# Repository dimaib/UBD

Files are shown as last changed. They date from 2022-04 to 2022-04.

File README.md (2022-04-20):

# Wireless access device
## Description
This system allows you to distribute people between warehouse equipment and give permission to control certain types of machines. It also allows you to take into account the working hours of employees and conduct convenient analytics according to these hours.
- The system consists of a device that controls the warehouse machine directly
	>The printed circuit board and circuit diagram of the device are created in [KiCad](https://www.kicad.org) 
	Firmware created in Keil uVision for ARM in C languages
- Server that receives data from devices and adds this data to the database
	>The server part was created in Visual Studio C ++, as a console application
- Client application that connects to the database and in a convenient form, displays
	>The client application was created in Visual Studio C#, as an application with a user interface

## Main view PCB
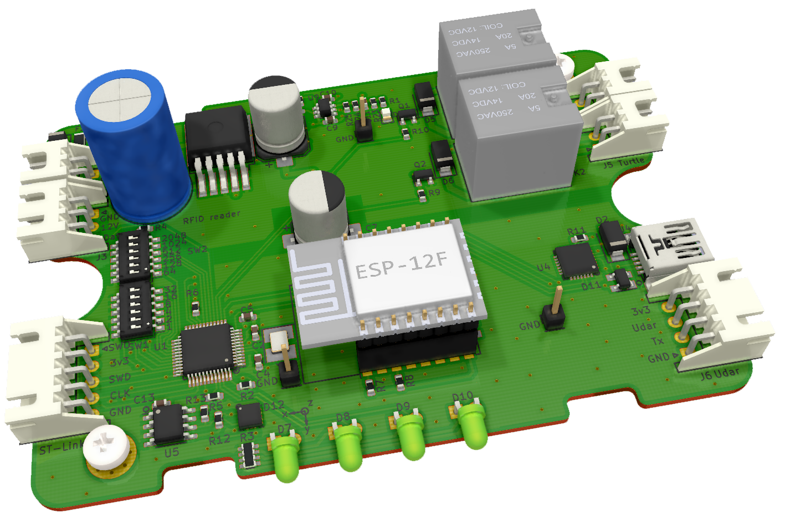
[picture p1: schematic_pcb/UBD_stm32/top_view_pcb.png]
PCB top

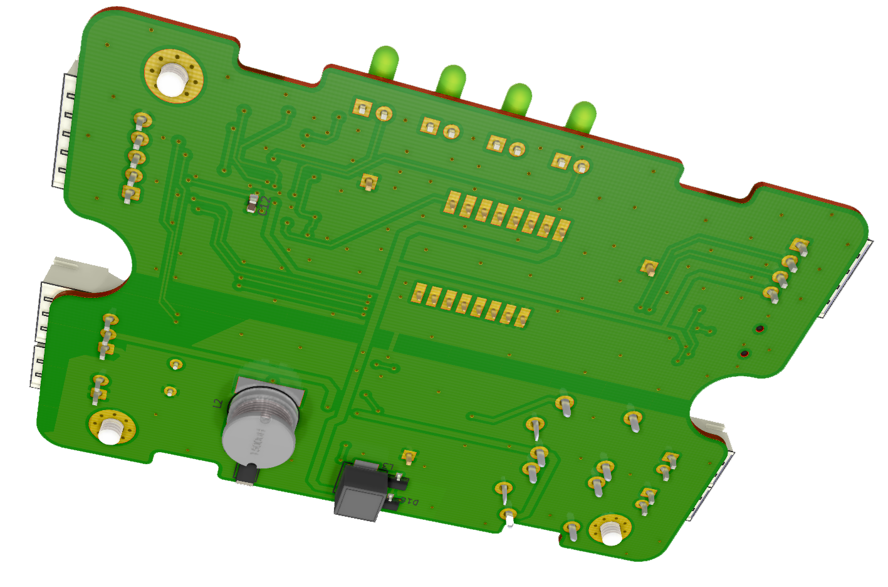
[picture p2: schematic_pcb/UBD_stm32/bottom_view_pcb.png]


## Main client app
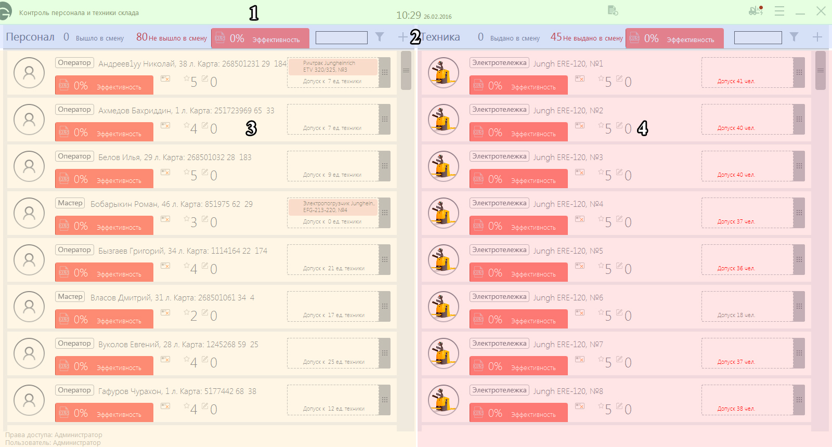
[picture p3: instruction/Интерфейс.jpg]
Main client app


>1. _Control panel_
>2. _General statistics panel for the warehouse_
>3. _Personnel control panel_
>4. _Equipment control panel_

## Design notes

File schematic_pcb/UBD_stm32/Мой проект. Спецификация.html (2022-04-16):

### Мой проект. Cпецификация

N | Название | Полное наименование | Количество | Обозначение
1 | +3.3V | | 18 | #PWR01 - #PWR03, #PWR05, #PWR011, #PWR013, #PWR015, #PWR020, #PWR022, #PWR0101 - #PWR0103, #PWR0106, #PWR0119, #PWR0120, #PWR0123, #PWR0125, #PWR0134
2 | +3V3 | | 1 | #PWR0126
3 | +5V | | 3 | #PWR019, #PWR021, #PWR024
4 | GND | | 32 | #PWR04, #PWR06 - #PWR08, #PWR010, #PWR012, #PWR014, #PWR016 - #PWR018, #PWR023, #PWR025, #PWR0104, #PWR0105, #PWR0107 - #PWR0112, #PWR0114 - #PWR0117, #PWR0121, #PWR0122, #PWR0124, #PWR0127, #PWR0128, #PWR0131 - #PWR0133
5 | +12V | | 5 | #PWR09, #PWR0113, #PWR0118, #PWR0129, #PWR0130
6 | 100 | | 1 | C1
7 | 220 | | 2 | C2, C3
8 | 1uF | | 3 | C4 - C6
9 | 100nF | | 1 | C7
10 | D_Schottky | | 3 | D1 - D3
11 | Red | | 2 | D12, D13
12 | LED | | 1 | D4
13 | D_Schottky | | 2 | D5, D6
14 | Red | | 4 | D7 - D10
15 | Fuse | | 1 | F1
16 | Для программирования | | 1 | J1
17 | Входной клемник | | 1 | J2
18 | Считыватель | | 1 | J3
19 | USB_B_Micro | | 1 | J4
20 | На релейной плате | | 1 | J5
21 | На основной плате | | 1 | J6
22 | G5LE-1 | | 2 | K1, K2
23 | 1000 | | 1 | L1
24 | 2200 | | 1 | L2
25 | BC817 | | 4 | Q1 - Q4
26 | 360 | | 8 | R1, R7 - R12, R15
27 | 1k | | 1 | R13
28 | 10k | | 6 | R2, R4 - R6, R14, R16
29 | 360 | | 1 | R3
30 | Выбор адреса | | 1 | SW1
31 | LM2576HVS-3.3 | | 1 | U1
32 | LM2576HVS-12 | | 1 | U2
33 | ESP-12F | | 1 | U3
34 | ATmega128-16AU | | 1 | U4
35 | LIS302 | | 1 | U5
36 | CH340G | | 1 | U6
37 | AP1117-33 | | 1 | U7
38 | 14.7456MHz | | 1 | Y1
39 | 12MHz | | 1 | Y2

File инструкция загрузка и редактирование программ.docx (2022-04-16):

Прошивка контроллеров Atmega.

На базе данных контроллеров разработаны устройства УБД и датчик удара. Для программирования этих контроллеров требуется следующий инструментарий:

- программатор для контроллеров AVR. Например, USBASP. Распиновка разъёма данного программатора, это стандартный ISP разъём:

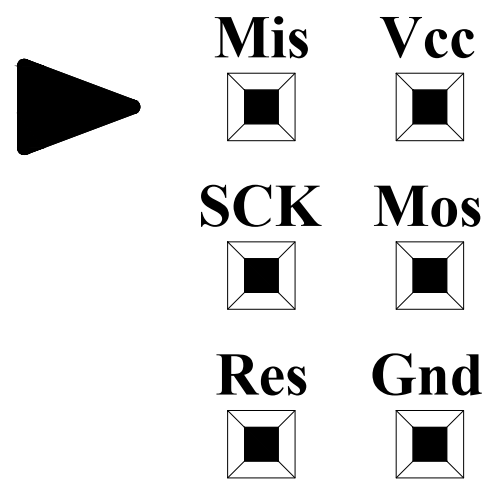
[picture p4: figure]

- переходник USB-UART. Например, на базе микросхемы ch340.
- программа для редактирования и компилирования программы контроллера BASCOM
- программа для редактирования и компилирования программы контроллера Atmel Studio
- программа для загрузки программы в контроллер ProgISP (стабильно работает 1.72 версия)
- программа для получения данных из серийного порта SerialMonitor (или любая аналогичная)
- программа для просмотра и редактирования схем и печатных плат проектов Kicad 5.1.4.1(не ниже)
- в некоторых случаях понадобится Arduino IDE, для редактирования и загрузки программ в Arduino

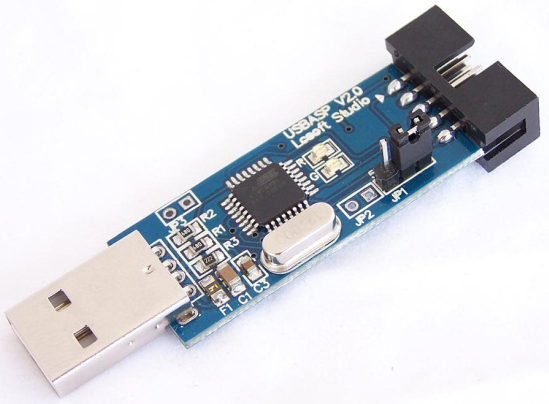
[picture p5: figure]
Картинки по запросу USBASP kicad

Для прошивки контроллера следует выбрать напряжение питания на программаторе, с помощью перемычки, 5В или 3.3В. Для того, что бы удостовериться в выборе напряжения, следует померить его на разъёме программатора. На рисунке показан общий вид программатора и перемычка выбора напряжения питания программируемого устройства.

Далее подключив разъём программатора к ISP разъёму устройства требуется запустить программу ProgISP. Общий внешний вид программы и необходимые настройки показаны на рисунке ниже.

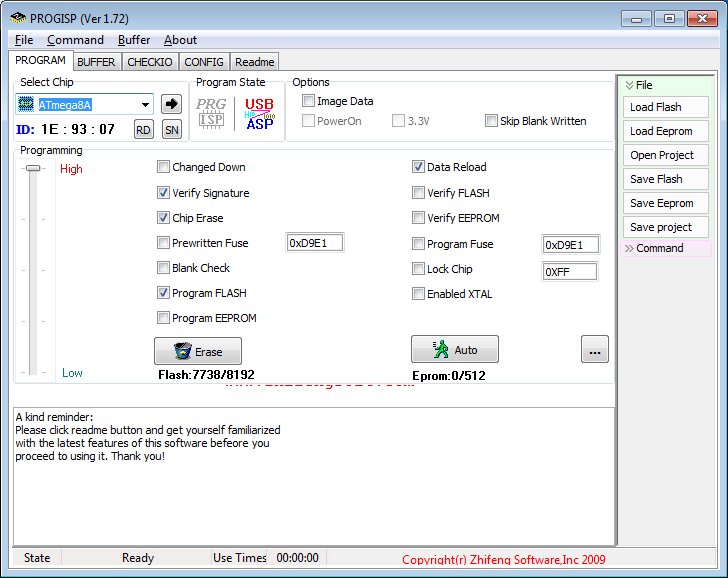
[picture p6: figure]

После запуска программы требуется выбрать программируемый контроллер из списка в поле “Select Chip”. Для датчика удара это Atmega8 или Atmega8A. Для УБД это Atmega128 или Atmega128A.

Далее требуется проверить правильность подключения программатора и работоспособность контроллера. Для этого достаточно считать его настройки (FUSES или фьюзы). Делается это следующим образом:

Фьюзы

Требуется зайти в окно настройки фьюзов нажатием на соответствующее поле.

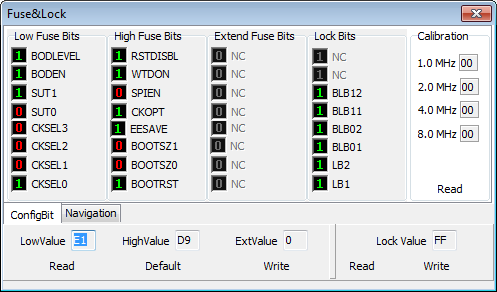
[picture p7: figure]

В открывшемся окне (Fuse&Lock) нажатием кнопки Read будут прочитаны настройки контроллера и подставлены в поля LowValue и HighValue. Возможные проблемы:

Ошибка “Programmer can not be found.” Говорит о том, что программатор либо не подключен, либо завис. Решается это подключением программатора или переподключением его в разъём USB.

Ошибка “Chip Enable Program Error” говорит о том, что контроллер не может быть прочитан. Причин этому может быть множество. Вот некоторые из них:

Контроллер плохо припаян к плате; на контроллер не приходит питание; в контролер загружены не корректные фьюзы (можно сразу менять контроллер); не правильно подключен разъём программатора; контроллер выведен из строя…….. и тд.

Также при множественном чтении настроек в поля LowValue и HighValue могут заноситься постоянно разные данные, это говорит о плохом питающем напряжении, к примеру, на контроллер не приходит линия Gnd или Vcc.

Если есть возможность несколько раз стабильно прочитать фьюзы из контроллера это говорит о том, что он исправен и готов к прошивке.

Для этого сначала требуется настроить эти самые фьюзы с помощью полей LowValue и HighValue. [Датчик удара: LowValue=E4 HighValue=D9] [УБД: LowValue=FF HighValue=C1 ExtValue=FF]. После заполнения данных полей нажать на кнопку “Write”. Если всё прошло без ошибок, то для контроля можно несколько раз прочитать фьюзы. После закрываем окно Fuse&Lock.

Далее требуется выбрать hex-файл скомпилированной программы. Это делается нажатием кнопки “Load Flash”, и в открывшемся окне указать путь до hex-файла.

Датчик удара […\UBD\Программы\Датчик удара\Accel_LIS302\LIS302DL.hex]

УБД […\UBD\Программы\Программа МК\WiFi.hex]

Чтобы загрузить hex-файл в контроллер нажимаем кнопку “Auto”, после завершения загрузки контроллер автоматически начнёт работу.

Редактирование программы для УБД

Проект для УБД можно открыть и редактировать средой BASCOM IDE.

Запустив данную среду программирования, следует открыть файл проекта. Файл-Открыть в окне появившемся окне указать тип файлов “Project files (*.prj)”. Путь …\UBD\Программы\Программа МК\UBD.prj.

В данном проекте, для настойки работоспособности устройства требуется настроить следующие константы и переменные:

Plata версия платы. 1-старая плата, 2-новая плата [WiFi]

Debug_info вывод отладочной информации в UART [WiFi]

Print_info вывод информации о состоянии устройства в UART [WiFi]

Wifi номер дампа для сетевых настроек [Vars]

Ud_eep если 0-не сохранять удар в eeprom, если 1-сохранять удар в eeprom [Vars]

Ud_on если 0-удар отключен, если 1-удар включен [Vars]

Ig_ud_off отключение зажигания при ударе 0-не отключается, 1-отключается [Vars]

Дампы сетевых настроек. Имеются три дампа в файле Data:

Ip_adr дамп IP-адресов сервера

Wifi_ap дамп имён точек доступа

Wifi_pass дамп паролей от точек доступа

Нумерация записей в дампе начинаются с нуля и выбираются с помощью переменной Wifi. К примеру, если задать данной переменной значение 2, то IP-сервера будет 192.168.0.30, имя точки доступа Kslift, пароль от точки доступа A0C4B096D4.

Ip_adr: IP-адреса сервера [Data]

Data _

"10.11.22.50", _

"10.0.0.3", _

"192.168.0.30", _

"192.168.1.20",

Wifi_ap: Имена точек доступа

Data _

"MJR-Sklad", _

"NETGEAR", _

"Kslift", _

"dimaib"

Wifi_pass: Пароли точек доступа

Data _

"DabuDaDe", _

"111222333444", _

"A0C4B096D4", _

"230988DVG"

После всех настроек сделанных в прошивке следует нажать клавишу F7, что запустит компиляцию. После удачной компиляции программу следует загрузить в контроллер.

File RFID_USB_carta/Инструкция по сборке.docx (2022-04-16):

После монтажа компонентов на печатную плату следует подключить её к считывателю RFID-карт MATRIX II. На рисунке 1 представлены места пайки.

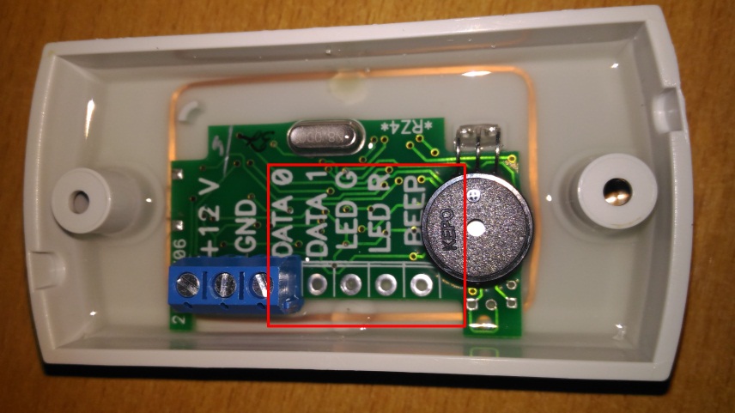
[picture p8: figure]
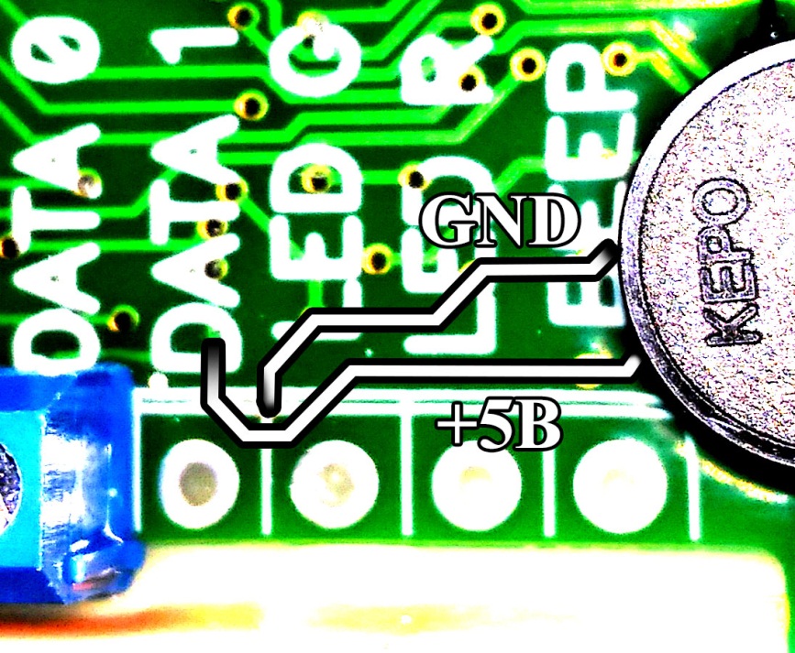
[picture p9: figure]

Клемма Rfid на плате соединяется с клеммой DATA 0

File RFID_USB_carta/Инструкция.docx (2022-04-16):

| Содержание

1. Назначение устройства
2. Комплектность
3. Технические характеристики

| Назначение устройства

Данное устройство предназначено для передачи на персональный компьютер в поле ввода идентификационного номера карты (RFID)

| Технические характеристики*

Длина кабеля | 1 метр
Размеры (ДхШхВ) | 85х43х17
Питание | 5В (USB)

| Общие указания по использованию устройства

Для работы устройства требуется наличие USB порта в ПК, с которым оно используется.

При первом подключении устройства в USB порт, происходит автоматическая установка драйверов. После установки устройство определяется как “Устройство ввода”. Круглый светодиод на лицевой панели отображает состояние NumLock в системе.

Что бы вставить идентификатор карты в текстовое поле с помощью данного устройства требуется активировать NumLock (светодиод NumLock на клавиатуре горит), далее вставить устройство в USB порт и дождаться пока загорится круглый, красный светодиод на лицевой панели, это свидетельствует, что устройство готово к работе. При горящем круглом светодиоде на передней панели, следует приложить карту к устройству, после этого в текстовое поле вставится её идентификационный код.

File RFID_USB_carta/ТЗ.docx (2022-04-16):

USB устройство для считывания RFID-карты

Требуется устройство для считывания RFID-карты и передачи данных по USB. USB устройство должно определяться как HID устройство ввода. Передача считанной карты происходит в активное текстовое поле в следующем формате: FF FF FF FF FF FF FF FF.

Питание устройства осуществляется от USB кабеля.

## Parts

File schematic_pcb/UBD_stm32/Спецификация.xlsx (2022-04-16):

Обозначение на схеме | Номинал | Корпус | Артикул | Ссылка | Цена, руб | Кол-во | Цена общая
C1 | 100uF | Capacitor_THT:C_Radial_D12.5mm_H20.0mm_P5.00mm | 9000291267 | https://www.chipdip.ru/product0/9000291267 | 28.00 ₽ | 1 | 28.00 ₽
> C3, C7 | 220uF | Capacitor_SMD:CP_Elec_8x10.5 | ECAP SMD, 220 мкФ, 25В | https://www.chipdip.ru/product0/57194 | 24.00 ₽ | 2 | 48.00 ₽
> C2, C4, C5 | 100n | Capacitor_SMD:C_0603_1608Metric | GRM188R71E104KA01D | https://www.chipdip.ru/product/grm188r71e104ka01d | 3.00 ₽ | 3 | 9.00 ₽
> C6, C12, C13 | 1uF | Capacitor_SMD:C_0603_1608Metric | GRM188R61E105KAADD | https://www.chipdip.ru/product/grm188r61e105k | 5.00 ₽ | 3 | 15.00 ₽
C8 | 10uF | Capacitor_SMD:C_0603_1608Metric | GRM188R61E106MA73D | https://www.chipdip.ru/product/grm21br61c106ke15l | 12.00 ₽ | 1 | 12.00 ₽
C9 | 0.01uF | Capacitor_SMD:C_0603_1608Metric | MLCC0.01uFX7R50V10%0603 | https://www.chipdip.ru/product0/9000143994 | 3.00 ₽ | 1 | 3.00 ₽
C10 | 22uF | Capacitor_SMD:C_0603_1608Metric | GRM188R60G226MEA0L | https://www.chipdip.ru/product/grm188r60g226mea0l | 13.00 ₽ | 1 | 13.00 ₽
C11 | 1000pF | Capacitor_SMD:C_0603_1608Metric | GRM1885C1H102JA01D | https://www.chipdip.ru/product/grm1885c1h102j | 2.00 ₽ | 1 | 2.00 ₽
> D1-D3, D5, D6 | Диод Шоттки | UBD:D_SMA | SS16 | https://www.chipdip.ru/product/ss16 | 4.00 ₽ | 5 | 20.00 ₽
D4 | LED | LED_SMD:LED_0805_2012Metric | KP-2012EC | https://www.chipdip.ru/product/kp-2012ec | 9.00 ₽ | 1 | 9.00 ₽
D7 | Светодиод красный | UBD:LED_D3.0mm_Horizontal_O1.27mm_Z2.0mm | GNL-3014SRD | https://www.chipdip.ru/product/gnl-3014srd | 4.00 ₽ | 1 | 4.00 ₽
D8 | Светодиод жёлтый | UBD:LED_D3.0mm_Horizontal_O1.27mm_Z2.0mm | GNL-3012GD | https://www.chipdip.ru/product/gnl-3012gd | 5.00 ₽ | 1 | 5.00 ₽
D9 | Светодиод зелёный | UBD:LED_D3.0mm_Horizontal_O1.27mm_Z2.0mm | GNL-3014YT | https://www.chipdip.ru/product/gnl-3014yt | 5.00 ₽ | 1 | 5.00 ₽
D10 | Светодиод синий | UBD:LED_D3.0mm_Horizontal_O1.27mm_Z2.0mm | GNL-3014UBD-TL | https://www.chipdip.ru/product/gnl-3014ubd-tl | 11.00 ₽ | 1 | 11.00 ₽
D11 | SP0503 | Package_TO_SOT_SMD:SOT-143 | SP0503BAHTG | https://www.chipdip.ru/product/sp0503bahtg | 44.00 ₽ | 1 | 44.00 ₽
> D15, D16 | Диод Шоттки | Diode_SMD:D_SOT-23_ANK | ZHCS1000TA | https://www.chipdip.ru/product/zhcs1000ta-sot23 | 4.00 ₽ | 2 | 8.00 ₽
F1 | Fuse 2A | Resistor_SMD:R_1206_3216Metric | Fuse 1.1A smd | https://ru.aliexpress.com/item/100-0805-1206-1812-0-05A-2A-0-1A-0-2A-0-5A-0/32894932841.html?s=p | 6.00 ₽ | 1 | 6.00 ₽
J1 | ST-Link | Connector_JST:JST_XH_S5B-XH-A_1x05_P2.50mm_Horizontal | ??? | https://www.tme.eu/ru/details/s5b-xh-a/razemy-signalnye-rastr-2-50mm/jst/s5b-xh-a-lf-sn https://www.tme.eu/ru/details/nx2501-05pfs/razemy-signalnye-rastr-2-50mm/joint-tech/a2501h-5p | 6+6 | 1 | 12.00 ₽
J2 | Ignition | Connector_JST:JST_XH_S2B-XH-A_1x02_P2.50mm_Horizontal | CWF-2R (DS1069-2 MR-A) CHU-2 (DS1069-2 F) | https://www.chipdip.ru/product/cwf-2r-ds1069-2-mr https://www.chipdip.ru/product/chu-2 | 6+6 | 1 | 12.00 ₽
J3 | Считыватель | Connector_JST:JST_XH_S3B-XH-A_1x03_P2.50mm_Horizontal | CWF-3R (DS1069-3 MR-A) CHU-3 (DS1069-3 F) | https://www.chipdip.ru/product/cwf-3r https://www.chipdip.ru/product/chu-3 | 5+5 | 1 | 10.00 ₽
J4 | USB_B_Micro | Connector_USB:USB_Mini-B_Lumberg_2486_01_Horizontal | MiniUSB-A | https://www.chipdip.ru/product/miniusb-a-5pin | 22.00 ₽ | 1 | 22.00 ₽
J5 | Turtle | Connector_JST:JST_XH_S2B-XH-A_1x02_P2.50mm_Horizontal | CWF-2R (DS1069-2 MR-A) CHU-2 (DS1069-2 F) | https://www.chipdip.ru/product/cwf-2r-ds1069-2-mr https://www.chipdip.ru/product/chu-2 | 6+6 | 1 | 12.00 ₽
J6 | Удар | Connector_JST:JST_XH_S4B-XH-A_1x04_P2.50mm_Horizontal | CWF-4R (DS1069-4 MR-A) CHU-4 (DS1069-4 F) | https://www.chipdip.ru/product/cwf-4r-ds1069-4-mr https://www.chipdip.ru/product/chu-4 | 6+6 | 1 | 12.00 ₽
J7 | Питание | Connector_JST:JST_XH_S2B-XH-A_1x02_P2.50mm_Horizontal | CWF-2R (DS1069-2 MR-A) CHU-2 (DS1069-2 F) | https://www.chipdip.ru/product/cwf-2r-ds1069-2-mr https://www.chipdip.ru/product/chu-2 | 6+6 | 1 | 12.00 ₽
> K1, K2 | NRP-18 | UBD:Relay_NRP-18 | NRP-18-C-12D-H | https://www.chipdip.ru/product/nrp-18-c-12d-s-h | 47.00 ₽ | 2 | 94.00 ₽
L2 | 1500uH | UBD:SDR_1006 | SDR1006-152KL | https://www.chipdip.ru/product/sdr1006-152kl-1500 | 45.00 ₽ | 1 | 45.00 ₽
L3 | 10uH | UBD:L_Vishay_IHLP-2525 | LQH66SN100M03L | https://www.chipdip.ru/product/lqh66sn100m | 74.00 ₽ | 1 | 74.00 ₽
> Q1, Q2 | BC817 | UBD:SOT-23 | BC817.215 | https://www.chipdip.ru/product/bc817.215 | 3.00 ₽ | 2 | 6.00 ₽
> R2, R4-R8, R11-R13, R25 | 10k | Resistor_SMD:R_0603_1608Metric | 0.063Вт 0603 10 кОм, 1% | https://www.chipdip.ru/product0/9000079736 | 0.90 ₽ | 10 | 9.00 ₽
R3 | 330 | Resistor_SMD:R_Array_Convex_4x0603 | CAY16-331J4 4х330 Ом | https://www.chipdip.ru/product/cay16-331j4 | 2.00 ₽ | 1 | 2.00 ₽
> R1, R9, R10 | 360 | Resistor_SMD:R_0603_1608Metric | 0.1Вт 0603 360 Ом, 1% | https://www.chipdip.ru/product0/9000079629 | 0.90 ₽ | 3 | 2.70 ₽
R22 | 100k | Resistor_SMD:R_0603_1608Metric | 0.1Вт 0603 100 кОм, 1% | https://www.chipdip.ru/product0/9000079760 | 0.90 ₽ | 1 | 0.90 ₽
R23 | 1.6k | Resistor_SMD:R_0603_1608Metric | 0.1Вт 0603 1.6 кОм, 1% | https://www.chipdip.ru/product0/770 | 0.90 ₽ | 1 | 0.90 ₽
R24 | 30k | Resistor_SMD:R_0603_1608Metric | 0.1Вт 0603 30 кОм, 1% | https://www.chipdip.ru/product0/9000079747 | 0.90 ₽ | 1 | 0.90 ₽
SW1 | Выбор адреса | Button_Switch_SMD:SW_DIP_SPSTx08_Slide_Omron_A6H-8101_W6.15mm_P1.27mm | NHDS-08 | http://www.platan.ru/cgi-bin/qwery.pl/id=105430408 | 70.00 ₽ | 1 | 70.00 ₽
U1 | STM32F103C8Tx | Package_QFP:LQFP-48_7x7mm_P0.5mm | STM32F103C8T6 | https://www.chipdip.ru/product/stm32f103c8t6 | 110.00 ₽ | 1 | 110.00 ₽
U2 | LM2576HVS-12 | Package_TO_SOT_SMD:TO-263-5_TabPin3 | LM2576HVT-12/NOPB | https://www.chipdip.ru/product/lm2576hvt-12-nopb | 330.00 ₽ | 1 | 330.00 ₽
U3 | ESP-12F | UBD:ESP-12E | ESP-12F | https://ru.aliexpress.com/item/1PCS-ESP-12F-ESP-12E-upgrade-ESP8266-Remote-Serial-Port-WIFI-Wireless-Module-ESP8266-4M-Flash/32808593889.html | 93.00 ₽ | 1 | 93.00 ₽
U4 | CP2102 | Package_DFN_QFN:QFN-28-1EP_5x5mm_P0.5mm_EP3.35x3.35mm | CP2102-GMR | https://www.chipdip.ru/product/cp2102-gmr | 110.00 ₽ | 1 | 110.00 ₽
U5 | AT24CS256 | Package_SO:SOIC-8_3.9x4.9mm_P1.27mm | AT24CS256 | https://www.chipdip.ru/product/at24cs02-sshm-t-microchip | 40.00 ₽ | 1 | 40.00 ₽
U9 | LM2734Y | Package_TO_SOT_SMD:TSOT-23-6 | LM2734YMK | https://www.chipdip.ru/product/lm2734ymk-nopb | 120.00 ₽ | 1 | 120.00 ₽
Y1 | 8.0MHz | UBD:Crystal_SMD_3225-2Pin_3.2x2.5mm_HandSoldering | NX3225GD-8MHz | https://www.chipdip.ru/product0/9000523940 | 13.00 ₽ | 1 | 13.00 ₽

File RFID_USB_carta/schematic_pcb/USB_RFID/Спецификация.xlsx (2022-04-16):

Спецификация для настольного считывателя карт
Наименование |  | Артикул | Ссылка | Кол-во общ | Цена шт | Кол-во | Цена общ
10uF 10V | Capacitor_Tantalum_SMD:CP_EIA-3216-18_Kemet-A | TECAP10/10VA10 | https://www.chipdip.ru/product0/868717967 | 12 | 12.00р. | 1 | 12.00р. | 144.00р.
33pF | Capacitor_SMD:C_0805_2012Metric | GRM2165C1H330JD01D | https://www.chipdip.ru/product/grm2165c1h330j | 24 | 2.00р. | 2 | 4.00р. | 96.00р.
3v6 | Diode_SMD:D_MiniMELF | BZV55C3V6 | https://www.chipdip.ru/product/bzv55c3v6 | 24 | 2.00р. | 2 | 4.00р. | 96.00р.
LED | LED_SMD:LED_0603_1608Metric | TO-1608BC-MYF | https://www.chipdip.ru/product/to-1608bc-myf | 12 | 3.00р. | 1 | 3.00р. | 36.00р.
Program | USB_RFID:PinHeader_2x03_P2.54mm_Vertical | PLD-6 (DS1021-2x3S) | https://www.chipdip.ru/product/pld-6 | 12 | 6.00р. | 1 | 6.00р. | 72.00р.
USB | USB_RFID:RFID | 18-1136 | https://www.chipdip.ru/product/18-1136-usb | 12 | 140.00р. | 1 | 140.00р. | 1680.00р.
10k | Resistor_SMD:R_0603_1608Metric | 0.063Вт 0603 10 кОм, 1% | https://www.chipdip.ru/product0/9000079736 | 12 | 0.90р. | 1 | 0.90р. | 10.80р.
68 | Resistor_SMD:R_0603_1608Metric | 0.063Вт 0603 68 Ом, 1% | https://www.chipdip.ru/product0/9000189750 | 24 | 0.90р. | 2 | 1.80р. | 43.20р.
1.5k | Resistor_SMD:R_0603_1608Metric | 0.063Вт 0603 1.5 кОм, 1% | https://www.chipdip.ru/product0/9000079716 | 12 | 0.90р. | 1 | 0.90р. | 10.80р.
360 | Resistor_SMD:R_0603_1608Metric | 0.063Вт 0603 360 Ом, 1% | https://www.chipdip.ru/product0/9000189778 | 12 | 0.90р. | 1 | 0.90р. | 10.80р.
SW_Push | USB_RFID:SW_SPST_PTS645 | L-KLS7-TS6604-7.0-180-T | https://www.chipdip.ru/product/swt-34 | 12 | 8.00р. | 1 | 8.00р. | 96.00р.
ATmega8-16AU | Package_QFP:TQFP-32_7x7mm_P0.8mm | ATmega8A-AU | https://www.chipdip.ru/product/atmega8a-au | 12 | 90.00р. | 1 | 90.00р. | 1080.00р.
12MHz | Crystal:Crystal_SMD_HC49-SD_HandSoldering | 12.000 МГц имп. HC-49SM | https://www.chipdip.ru/product/12mhz-hc-49sm | 12 | 15.00р. | 1 | 15.00р. | 180.00р.
 |  |  |  |  | Итого: |  | 286.50р. | 3555.60р.

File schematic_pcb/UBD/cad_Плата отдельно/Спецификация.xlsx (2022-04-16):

Наименование | Корпус | Артикул | Ссылка | Цена | Кол-во | Устройств | Цена
100uF | Capacitor_THT:C_Radial_D8.0mm_H11.5mm_P3.50mm | B41851F8107M000 | https://www.chipdip.ru/product0/9000188152 | 14 | 1 | 10 | 140
220uF | Capacitor_SMD:CP_Elec_8x10.5 | ECAP SMD, 220 мкФ, 25В | https://www.chipdip.ru/product0/57194 | 24 | 1 | 10 | 240
1uF | Capacitor_SMD:C_0805_2012Metric | GRM21BR71C105KA01K | https://www.chipdip.ru/product/grm21br71c105k | 4 | 2 | 10 | 80
100nF | Capacitor_SMD:C_0805_2012Metric | MLCC1000pF50VNP05%0805 | https://www.chipdip.ru/product0/522764173 | 4 | 1 | 10 | 40
10uF | Capacitor_SMD:C_0805_2012Metric | GRM21BR71C105KA01K | https://www.chipdip.ru/product/grm21br71c105k | 4 | 3 | 10 | 120
0.01uF | Capacitor_SMD:C_0805_2012Metric | GRM21BR71C105KA01K | https://www.chipdip.ru/product/grm21br71c105k | 4 | 1 | 10 | 40
22uF | Capacitor_SMD:C_0805_2012Metric | GRM21BR71C105KA01K | https://www.chipdip.ru/product/grm21br71c105k | 4 | 1 | 10 | 40
1000pF | Capacitor_SMD:C_0805_2012Metric | GRM21BR71C105KA01K | https://www.chipdip.ru/product/grm21br71c105k | 4 | 1 | 10 | 40
Диод Шоттки | Diode_SMD:D_SMA | SS16 | https://www.chipdip.ru/product/ss16 | 4 | 4 | 10 | 160
LED | LED_SMD:LED_0805_2012Metric | KP-2012EC | https://www.chipdip.ru/product/kp-2012ec | 9 | 1 | 10 | 90
Светодиод красный | UBD:LED_D3.0mm_Horizontal_O1.27mm_Z2.0mm | GNL-3014SRD | https://www.chipdip.ru/product/gnl-3014srd | 4 | 1 | 10 | 40
Светодиод жёлтый | UBD:LED_D3.0mm_Horizontal_O1.27mm_Z2.0mm | GNL-3012GD | https://www.chipdip.ru/product/gnl-3012gd | 5 | 1 | 10 | 50
Светодиод зелёный | UBD:LED_D3.0mm_Horizontal_O1.27mm_Z2.0mm | GNL-3014YT | https://www.chipdip.ru/product/gnl-3014yt | 5 | 1 | 10 | 50
Светодиод синий | UBD:LED_D3.0mm_Horizontal_O1.27mm_Z2.0mm | GNL-3014UBD-TL | https://www.chipdip.ru/product/gnl-3014ubd-tl | 11 | 1 | 10 | 110
BAS321 | UBD:D_SOD-323_HandSoldering | BAS321.115 | https://www.chipdip.ru/product/bas321.115 | 8 | 2 | 10 | 160
AZ23C3V3 | Package_TO_SOT_SMD:SOT-23 | AZ23C3V3-E3-18 | https://www.chipdip.ru/product/az23-c3v3 | 4 | 2 | 10 | 80
Диод Шоттки | Diode_SMD:D_SOT-23_ANK | ZHCS1000TA | https://www.chipdip.ru/product/ss16 | 4 | 2 | 10 | 80
Fuse | Resistor_SMD:R_1206_3216Metric | Fuse 1.1A smd | https://ru.aliexpress.com/item/100-0805-1206-1812-0-05A-2A-0-1A-0-2A-0-5A-0/32894932841.html?s=p | 6 | 1 | 10 | 60
Для программирования | UBD:PinHeader_2x03_P2.54mm_Vertical | PLD-6 (DS1021-2x3S) | https://www.chipdip.ru/product/pld-6 | 6 | 2 | 10 | 120
Считыватель | UBD:JST_XH_B3B-XH-A_1x03_P2.50mm_Vertical | CHU-3 (DS1069-3 F) | https://www.chipdip.ru/product/chu-3 | 5 | 1 | 10 | 50
Считыватель | UBD:JST_XH_B3B-XH-A_1x03_P2.50mm_Vertical | CWF-3 (DS1069-3 M) | https://www.chipdip.ru/product/cwf-3 | 5 | 1 | 10 | 50
USB_B_Micro | UBD:USB_Micro | L-KLS1-233-0-0-1-T | https://www.chipdip.ru/product/micro-usb-5s-b | 6 | 1 | 10 | 60
Conn_01x02 | UBD:DG_308_2 | 308-021-14 | https://www.chipdip.ru/product/308-021-12-14 | 14 | 6 | 10 | 840
Удар | UBD:JST_XH_B4B-XH-A_1x04_P2.50mm_Vertical | CHU-4 (DS1069-4 F) | https://www.chipdip.ru/product/chu-4 | 5 | 1 | 10 | 50
Удар | UBD:JST_XH_B4B-XH-A_1x04_P2.50mm_Vertical | CWF-4 (DS1069-4 M) | https://www.chipdip.ru/product/cwf-4 | 5 | 1 | 10 | 50
NRP-18 | UBD:Relay_NRP-18 | NRP-18-C-12D-H | https://www.chipdip.ru/product/nrp-18-c-12d-s-h | 47 | 2 | 10 | 940
2200 | UBD:L_10.4x10.4_H4.8 | SDR0805-222KL, 2200 мкГн | https://www.chipdip.ru/product/sdr0805-222kl | 30 | 1 | 10 | 300
10uH | UBD:L_Vishay_IHLP-2525 | LQH66SN100M03L | https://www.chipdip.ru/product/lqh66sn100m | 74 | 1 | 10 | 740
BC817 | UBD:SOT-23 | BC817.215 | https://www.chipdip.ru/product/bc817.215 | 3 | 4 | 10 | 120
10k | Resistor_SMD:R_0603_1608Metric | 0.063Вт 0603 10 кОм, 1% | https://www.chipdip.ru/product0/9000079736 | 0.9 | 13 | 10 | 117
360 | Resistor_SMD:R_Array_Convex_4x0603 | CAY16-331J4 4х330 Ом | https://www.chipdip.ru/product/cay16-331j4 | 2 | 1 | 10 | 20
360 | Resistor_SMD:R_0603_1608Metric | 0.063Вт 0603 360 Ом, 1% | https://www.chipdip.ru/product0/9000079629 | 0.9 | 11 | 10 | 99
10k | Resistor_SMD:R_0603_1608Metric | 0.063Вт 0603 1 кОм, 1% | https://www.chipdip.ru/product0/9000079676 | 0.9 | 1 | 10 | 9
1k | Resistor_SMD:R_0603_1608Metric | 0.063Вт 0603 1 кОм, 1% | https://www.chipdip.ru/product0/9000079676 | 0.9 | 2 | 10 | 18
360 | Resistor_SMD:R_0603_1608Metric | 0.063Вт 0603 10 кОм, 1% | https://www.chipdip.ru/product0/9000079736 | 0.9 | 1 | 10 | 9
100k | Resistor_SMD:R_0603_1608Metric | 0.063Вт 0603 10 кОм, 1% | https://www.chipdip.ru/product0/9000079736 | 0.9 | 1 | 10 | 9
1.6k | Resistor_SMD:R_0603_1608Metric | 0.063Вт 0603 10 кОм, 1% | https://www.chipdip.ru/product0/9000079736 | 0.9 | 1 | 10 | 9
30k | Resistor_SMD:R_0603_1608Metric | 0.063Вт 0603 10 кОм, 1% | https://www.chipdip.ru/product0/9000079736 | 0.9 | 1 | 10 | 9
Выбор адреса | UBD:SW_DIP_SPSTx08_Slide_Omron_A6H-8101_W6.15mm_P1.27mm | NHDS-08 | http://www.platan.ru/cgi-bin/qwery.pl/id=105430408 | 70 | 1 | 10 | 700
LM2576HVS-12 | Package_TO_SOT_SMD:TO-263-5_TabPin3 | LM2576HVT-12/NOPB | https://www.chipdip.ru/product/lm2576hvt-12-nopb | 330 | 1 | 10 | 3300
ESP-12F | UBD:ESP-12E | ESP-12F | https://ru.aliexpress.com/item/1PCS-ESP-12F-ESP-12E-upgrade-ESP8266-Remote-Serial-Port-WIFI-Wireless-Module-ESP8266-4M-Flash/32808593889.html | 93 | 1 | 10 | 930
ATmega128-16AU | Package_QFP:TQFP-64_14x14mm_P0.8mm | ATmega128A-AU | https://www.chipdip.ru/product/atmega128a-au | 260 | 1 | 10 | 2600
LIS302 | UBD:LGA-14_3x5mm_P0.8mm_LayoutBorder1x6y | LIS302DLTR | https://www.chipdip.ru/product/lis302dltr | 64 | 2 | 10 | 1280
CH340G | Package_SO:SOIC-16_3.9x9.9mm_P1.27mm | CH340G | https://ru.aliexpress.com/item/5-CH340G-16-CH340/32985956586.html?s=p | 20 | 1 | 10 | 200
AP1117-33 | Package_TO_SOT_SMD:SOT-223-3_TabPin2 | AMS1117-3.3 | https://www.chipdip.ru/product/ams1117-3.3 | 17 | 1 | 10 | 170
LMV321 | Package_TO_SOT_SMD:SOT-23-5 | LMV321ILT | https://www.chipdip.ru/product/lmv321ilt | 15 | 2 | 10 | 300
LM2734Y | UBD:TSOT-23-6 | LM2734YMK | https://www.chipdip.ru/product/lm2734ymk-nopb | 120 | 1 | 10 | 1200
14.7456MHz | UBD:Crystal_SMD_HC49-SD | 14.7456 МГц имп. HC-49SM | https://www.chipdip.ru/product/14.7456mhz-hc-49sm | 18 | 1 | 10 | 180
12MHz | UBD:Crystal_SMD_3225-4Pin_3.2x2.5mm_HandSoldering | NX3225GA-12MHZ STD-CRG-2 | https://www.chipdip.ru/product0/9000523957 | 12 | 1 | 10 | 120
3V3 | Diode_SMD:D_MiniMELF | AZ23C3V3-E3-18 | https://www.chipdip.ru/product/az23-c3v3 | 4 | 1 | 10 | 40
47uH | Inductor_SMD:L_1812_4532Metric | LQM21NNR47K10D | https://www.chipdip.ru/product/lqm21nnr47k | 6 | 1 | 10 | 60
330 | Resistor_SMD:R_0805_2012Metric | 0.125Вт 0805 330 Ом, 1% | https://www.chipdip.ru/product0/9000079474 | 0.9 | 1 | 10 | 9
ATmega8A | Package_QFP:TQFP-32_7x7mm_P0.8mm | ATmega8A-AU | https://www.chipdip.ru/product/atmega8a-au | 90 | 1 | 10 | 900
LED | LED_SMD:LED_0805_2012Metric | TO-2013BC-MYF | https://www.chipdip.ru/product/to-2013bc-myf | 3 | 2 | 10 | 60
LED | Accel:LED_D3.0mm_Horizontal_O1.27mm_Z6.0mm | GNL-3014SRT | https://www.chipdip.ru/product/gnl-3014srt | 4 | 1 | 10 | 40
 |  |  | Итого: | 17328.00р.

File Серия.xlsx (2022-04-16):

Перечень работ по подготовке устройств для склада в Торжке
# | Наименование работ | 1 | 2 | 3 | 4 | 5 | 6 | 7 | 8 | 9 | 10 | 11 | 12 | 13 | 14 | 15 | 16 | 17 | 18 | 19 | 20
1. | Корпус устройства
1.1 | Просверлить отверстия по шаблону 3мм
1.2 | Просверлить отверстия для сальников и нарезать резьбу М12
1.3 | Вкрутить сальники удлинёной головкой и рассверлить их до 8мм
1.4 | Вклеить светодиоды термоклеем КОЗС
1.5 | Подготовить шлейф под светодиоды. 5 Пин 100мм
1.6 | Нарезать, залудить, припаять
1.7 | Просверилть отверстия под крепления платы по диагонали
1.8 | Приклеить стойки для платы
2. | Датчик удара
2.1 | Просверилть отверстие под сальник 12мм
2.2 | Зафиксировать сальники в коробке
2.3 | Вытравить платы
2.4 | Спаять платы, протестировать
2.5 | Подготовить кабель, припаять/подключить к плате
2.6 | Расположить в коробке
3. | Дополнительное реле
3.1 | Спаять дополнительные реле
3.2 | Переделать платы под дополнительное реле
4. | Кабель для программирования
4.1 | Нарезать кабель. Шлейф 5 Пин, 600мм
4.2 | Нарезать термоусадку
4.3 | Припаять кабель к разъёмам вместе с термоусадкой
5. | Плата устройства
5.1 | Подготовить или починить плату УБД
5.2
6. | Считыватель
6.1

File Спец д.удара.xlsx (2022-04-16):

Датчик удара
Тип элемента | Кол-во | Комплектов | Доп. | Всего | Цена | Артикул | Ссылка | Цена всё
LIS302 | 1 | 20 |  | 20 | 65 | LIS302DLTR | https://www.chipdip.ru/product/lis302dltr | 1300
Atmega8 | 1 | 20 |  | 20 | 90 | ATmega8A-AU | https://www.chipdip.ru/product/atmega8a-au | 1800
BC817 | 1 | 20 |  | 20 | 3 | BC817-16.215 | https://www.chipdip.ru/product/bc817-16-nxp | 60
Светодиод 3мм | 1 | 20 |  | 20 | 4 | GNL-3014SRT | https://www.chipdip.ru/product/gnl-3014srt | 80
Светодиод SMD | 2 | 20 |  | 40 | 3 | TO-2013BC-MYF | https://www.chipdip.ru/product/to-2013bc-myf | 120
Резистор 360Ом 0603 | 4 | 20 |  | 80 | 0.9 | 0.063Вт 0603 360 Ом, 1% | https://www.chipdip.ru/product0/9000079629 | 72
Резистор 10кОм 0603 | 5 | 20 |  | 100 | 0.9 | 0.063Вт 0603 10 кОм, 1% | https://www.chipdip.ru/product0/9000079736 | 90
Резистор 1кОм 0603 | 1 | 20 |  | 20 | 0.9 | 0.063Вт 0603 1 кОм, 1% | https://www.chipdip.ru/product0/9000079676 | 18
1117-33 | 1 | 20 |  | 20 | 17 | AMS1117-3.3 | https://www.chipdip.ru/product/ams1117-3.3 | 340
1uF 0805 | 2 | 20 |  | 40 | 4 | GRM21BR71C105KA01K | https://www.chipdip.ru/product/grm21br71c105k | 160
10uF tantal type A | 3 | 20 |  | 60 | 12 | TECAP10/10VA10 | https://www.chipdip.ru/product0/868717967 | 720
Индуктивность 47mcH | 1 | 20 |  | 20 | 6 | LQM21NNR47K10D | https://www.chipdip.ru/product/lqm21nnr47k | 120
Разъём на плату угловой 2х3 | 1 | 20 |  | 20 | 6 | PLD-6 (DS1021-2x3S) | https://www.chipdip.ru/product/pld-6 | 120
Клеммник 1х2 | 1 | 20 |  | 20 | 12 | 308-021-14 | https://www.chipdip.ru/product/308-021-12-14 | 240
Клеммник 1х3 | 1 | 20 |  | 20 | 25 | 308-031-14 (DG308-2.54-03P) | https://www.chipdip.ru/product/308-031-14-dg308-2.54-03p | 500
Корпус | 1 | 20 |  | 20 | 18 | G252515B | https://www.chipdip.ru/product/g252515b | 360
Сальник | 1 | 20 |  | 20 | 12 | PG-7 | https://www.chipdip.ru/product/pg-7 | 240
Диод шоттки SS16 | 1 | 20 |  | 20 | 4 | SS16 | https://www.chipdip.ru/product/ss16 | 80
Зенер 3в3 | 1 | 20 |  | 20 | 4 | AZ23C3V3-E3-18 | https://www.chipdip.ru/product/az23-c3v3 | 80
Диод | 1 | 20 |  | 20 | 8 | BAS321.115 | https://www.chipdip.ru/product/bas321.115 | 160
Опереационный усилитель | 1 | 20 |  | 20 | 14 | LMV321ILT | https://www.chipdip.ru/product/lmv321ilt | 280
 |  |  |  |  |  |  | Итого: | 6940

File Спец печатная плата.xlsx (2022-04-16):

ПЕРЕЧЕНЬ ЭЛЕМЕНТОВ ПО ТИПУ ДЛЯ ПЕЧАТНОЙ ПЛАТЫ
Обозначение позиции | Кол-во | Тип элемента | Корпус | Примечание | Комплектов | Доп. | Всего | Цена | Артикул | Ссылка | Цена всё
R6, R10 | 2 | 0.063Вт 0603 2 кОм, 1%, Чип резистор (SMD) | 6030 |  | 12 |  | 24 | 0.9 | 0.063Вт 0603 2 кОм, 1% | https://www.chipdip.ru/product0/9000079719 | 21.6
R7, R8, R12, R20 | 4 | 0.063Вт 0603 10 кОм, 1%, Чип резистор (SMD) | 6030 | +1 | 12 |  | 48 | 0.9 | 0.063Вт 0603 10 кОм, 1% | https://www.chipdip.ru/product0/9000079736 | 43.2
R1-R4, R11, R13, R16, R18 | 8 | 0.063Вт 0603 360 Ом, 1%, Чип резистор (SMD) | 6030 | +1 | 12 |  | 96 | 0.9 | 0.063Вт 0603 360 Ом, 1% | https://www.chipdip.ru/product0/9000079629 | 86.4
R5, R9, R15 | 3 | 0.063Вт 0603 1 кОм, 1%, Чип резистор (SMD) | 6030 |  | 12 |  | 36 | 0.9 | 0.063Вт 0603 1 кОм, 1% | https://www.chipdip.ru/product0/9000079676 | 32.4
R14 | 1 | 0.063Вт 0603 3 кОм, 1%, Чип резистор (SMD) | 6030 |  | 12 |  | 12 | 0.9 | 0.063Вт 0603 3 кОм, 1% | https://www.chipdip.ru/product0/9000079723 | 10.8
C2, C3 | 2 | Кер.ЧИП конд. 1 мкФ X7R 10% 16В 0805 | 0805 |  | 12 |  | 24 | 4 | GRM21BR71C105KA01K | https://www.chipdip.ru/product/grm21br71c105k | 96
C6 | 1 | ECAP (К50-35), 100 мкФ, 63 В, 105°C |  |  | 12 |  | 12 | 14 | ECAP100uF/63V,105°C | https://www.chipdip.ru/product0/395734888 | 168
C5 | 1 | ECAP (К50-35 мини), 220 мкФ, 10 В, 6х7мм | 6х7мм |  | 12 |  | 12 | 4 | JRK1A221M02500600070000B | https://www.chipdip.ru/product0/33102 | 48
C1, C4 | 2 | TECAP, 4.7 мкФ, 10 В, тип A, 10%, Конденсатор танталовый SMD | smd a |  | 12 |  | 24 | 14 | TECAP4.7/10VA10 | https://www.chipdip.ru/product0/6038 | 336
D1-D4 | 4 | SS16, Диод Шоттки 1A 60В [SMA / DO-214AC] | DO-214AC |  | 12 |  | 48 | 4 | SS16 | https://www.chipdip.ru/product/ss16 | 192
D5 | 1 | KPT-3216CGCK светодиод зеленый 3.2х1.6мм 50мКд SMD | 1206 | Любой светодиод, который подойдёт по типоразмеру | 12 |  | 12 | 3 | TO-1608BC-MYF | https://www.chipdip.ru/product/to-1608bc-myf | 36
VT1, VT2, VT3 | 3 | BC817.215, Транзистор NPN 45В 0.5А [SOT-23] | SOT-23 | +1 | 12 |  | 36 | 3 | BC817.215 | https://www.chipdip.ru/product/bc817.215 | 108
U1 | 1 | ATmega128A-AU | TQFP-64 |  | 12 |  | 12 | 260 | ATmega128A-AU | https://www.chipdip.ru/product/atmega128a-au | 3120
U2 | 1 | LM2596HVGR-ADJ | TO-263 |  | 12 |  | 12 | 270 | LM2575HVT-ADJ/NOPB | https://www.chipdip.ru/product/lm2575hvt-adj-nopb | 3240
U3 | 1 | AMS1117-3.3, Линейный регулятор с малым падением напряжения, 800мА, 3.3В, [SOT-223] | SOT-223 |  | 12 |  | 12 | 17 | AMS1117-3.3 | https://www.chipdip.ru/product/ams1117-3.3 | 204
Z1 | 1 | 14.7456 МГц (усечен.) HC-49S, кварцевый резонатор | hc-49s |  | 12 |  | 12 | 14 | 14.7456 МГц (усечен.) HC-49S | https://www.chipdip.ru/product/14.7456mhz-hc-49s | 168
L1 | 1 | B82477G4684M, 680 мкГн, 0.68 А, 12.8х12.8, Катушка индуктивности SMD |  | Диаметр (ширина)корпуса 7.8мм | 12 |  | 12 |  | B82477G4684M | https://www.chipdip.ru/product/b82477g4684m | 0
F1 | 1 | MF-R090, 0.9 А, Предохранитель самовосстанавливающийся, MultiFuse |  |  | 12 |  | 12 | 22 | MF-R090, 0.9 А | https://www.chipdip.ru/product/mf-r090 | 264
 | 5 | DG141V-2.54-02P, Клеммник нажимной, 2-контакный, шаг 2,54мм |  |  | 12 |  | 60 | 24 | L-KLS2-141V-2.54-02P-4 | https://www.chipdip.ru/product/kls2-141v-2.54-02p-4-dg141v-2.54-02p | 1440
 | 1 | PBS2-25 (DS1026 01 1x25), Гнездо на плату 2мм 1х25 прямое |  | Режется по 8 отверстий. На одну плату 2 линейки по 8 отверстий | 12 |  | 12 | 30 | PBS2-25 (DS1026 01 1x25) | https://www.chipdip.ru/product/pbs2-25 | 360
 | 1 | PLS2-40 (DS1025-01-1x40), Вилка штыревая 2мм 1х40 прямая |  | Режется по 8 пинов. На одну плату 2 линейки по 8 пинов | 12 |  | 12 | 15 | PLS2-40 (DS1025-01-1x40) | https://www.chipdip.ru/product/pls2-40 | 180
 | 1 | PLD-6 (DS1021-2x3S), Вилка штыревая 2.54мм 2x3 прямая тип1 |  |  | 12 |  | 12 | 6 | PLD-6 (DS1021-2x3S) | https://www.chipdip.ru/product/pld-6 | 72
 | 1 | ESP-12E, Встраиваемый Wi-Fi модуль на базе чипа ESP8266 |  |  | 12 |  | 12 | 90 |  | https://ru.aliexpress.com/item/1PCS-ESP-12F-ESP-12E-upgrade-ESP8266-Remote-Serial-Port-WIFI-Wireless-Module-ESP8266-4M-Flash/32808593889.html | 1080
 | 1 | Корпус |  |  | 20 |  | 20 |  |  |  | 0
 | 2 | Сальник |  |  | 20 |  | 40 | 12 | PG-7 | https://www.chipdip.ru/product/pg-7 | 480
 | 1 | Светодиод красный |  | Паяется на шлейф 100мм | 20 |  | 20 | 4 | GNL-3014SRD | https://www.chipdip.ru/product/gnl-3014srd | 80
 | 1 | Светодиод жёлтый |  | Паяется на шлейф 100мм | 20 |  | 20 | 5 | GNL-3012GD | https://www.chipdip.ru/product/gnl-3012gd | 100
 | 1 | Светодиод зелёный |  | Паяется на шлейф 100мм | 20 |  | 20 | 5 | GNL-3014YT | https://www.chipdip.ru/product/gnl-3014yt | 100
 | 1 | Светодиод синий |  | Паяется на шлейф 100мм | 20 |  | 20 | 11 | GNL-3014UBD-TL | https://www.chipdip.ru/product/gnl-3014ubd-tl | 220
 | 1 | Разъём для светодиодов 1х5 |  | Паяется на шлейф 100мм | 20 |  | 20 | 28 | BLS-5 (DS1071-1x5) | https://www.chipdip.ru/product/bls-5 | 560
 | 4 | Стойка для платы пластиковая |  | Клеится на крышку | 20 |  | 80 | 4 | KLS8-0115-LED-3 (ф7-4x3) | https://www.chipdip.ru/product/kls8-0115-led-3 | 320
 | 2 | Болт М3 для крепления коробки |  |  | 20 |  | 40 |  |  |  | 0
 |  |  |  |  |  |  |  |  |  | Итого: | 13166.4

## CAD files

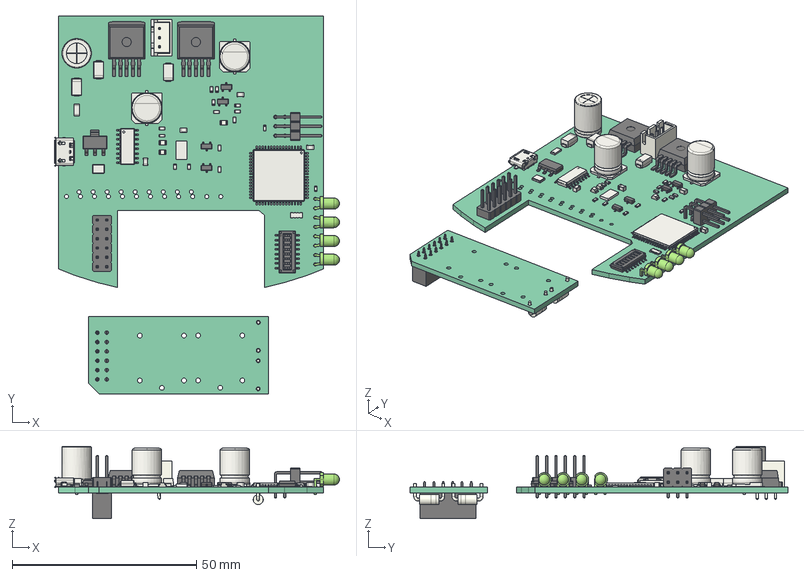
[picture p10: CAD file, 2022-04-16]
schematic_pcb/UBD/cad_RFID+Плата/UBD.FCStd
77.4 x 102.6 x 19.6 mm
Pcb
D10_LED_D3.0mm_Horizontal_O1.27mm_Z2.0mm_5CC0D89F
D9_LED_D3.0mm_Horizontal_O1.27mm_Z2.0mm_5CC0D84B
D8_LED_D3.0mm_Horizontal_O1.27mm_Z2.0mm_5CC0D875
U7_SOT_223_5CF7EDB7
Y2_Crystal_SMD_3225-4Pin_3.2x2.5mm_HandSoldering_5CF86F71
R14_R_0603_1608Metric_5CF82F8B
C7_C_0805_2012Metric_5CF809CB
D7_LED_D3.0mm_Horizontal_O1.27mm_Z2.0mm_5CC0D821
U5_LGA_14_3x5mm_P08mm_LayoutBorder1x6y_5CC20794
J1_PinHeader_2x03_P254mm_Horizontal_5CB1C2C8
Q2_SOT_23_5CB31C95
C1_C_Radial_D80mm_H115mm_P350mm_5CB1C22C
D1_D_SMA_5CB1C258
D2_D_SMA_5CB1C270
D3_D_SMA_5CB1C288
D4_LED_0805_2012Metric_5CB1C29B
F1_R_1206_3216Metric_5CB1C2AC
Q1_SOT_23_5CC2336D
R1_R_0603_1608Metric_5CB1C362
R2_R_0603_1608Metric_5CB1C373
R7_R_0603_1608Metric_5CB1C3C8
R8_R_0603_1608Metric_5CB1C3D9
U1_TO_263_5_TabPin3_5CB1C409
U2_TO_263_5_TabPin3_5CB1C439
U4_TQFP_64_14x14mm_P08mm_5CB1C4CB
C2_CP_Elec_8x105_5CB255DB
C3_CP_Elec_8x105_5CB25603
C5_C_0805_2012Metric_5CB310DE
C6_C_0805_2012Metric_5CC2103F
R9_R_0603_1608Metric_5CB31CA6
R10_R_0603_1608Metric_5CB31CB7
J6_PinHeader_2x06_P254mm_Vertical_5CC018D7
R3_R_Array_Convex_4x0603_5CC0F04C
SW1_SW_DIP_SPSTx08_Slide_Omron_A6H_8101_W615mm_P127mm_5CC147D4
R4_R_0603_1608Metric_5CC1F46F
C4_C_0805_2012Metric_5CC20772
D12_LED_0805_2012Metric_5CC22525
D13_LED_0805_2012Metric_5CC207BA
R5_R_0603_1608Metric_5CC207CB
R6_R_0603_1608Metric_5CC207DC
R11_R_0603_1608Metric_5CC2468A
R12_R_0603_1608Metric_5CC207FE
J3_JST_B3B_XH_A_5CC1F7AD
J4_USB_Micro-B_Molex_47346-0001_5CF7ED56
Q3_SOT_23_5CF82FEE
R13_R_0603_1608Metric_5CF7ED7C
U6_SOIC_16_39x99mm_P127mm_5CF7EDA1
Q4_SOT_23_5CF93CE1
R15_R_0603_1608Metric_5CF93CF2
R16_R_0603_1608Metric_5CF93D03
J5_PinSocket_2x06_P254mm_Vertical_5CBEBC73
D5_D_DO-41_SOD81_P7.62mm_Horizontal_5CBEEC2B
D6_D_DO-41_SOD81_P7.62mm_Horizontal_5CBEEC4A

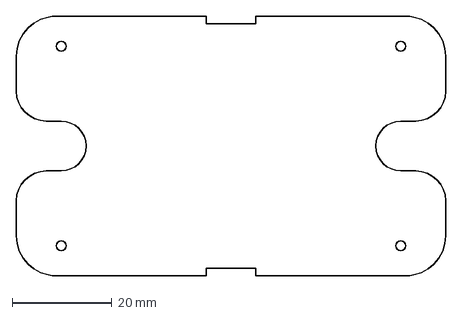
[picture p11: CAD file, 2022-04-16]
schematic_pcb/UBD/cad_Плата отдельно/Контур платы.dxf
86.0 x 52.0 mm

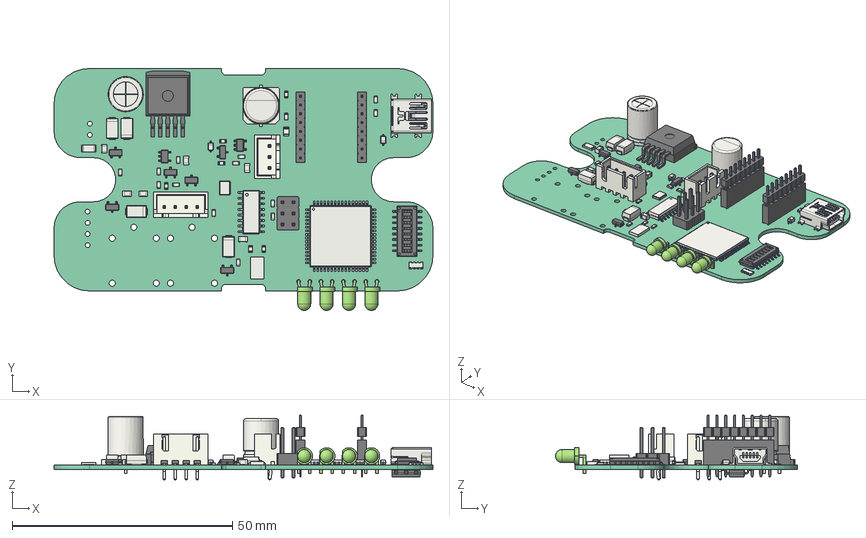
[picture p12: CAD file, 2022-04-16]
schematic_pcb/UBD/cad_Плата отдельно/UBD.FCStd
86.0 x 54.9 x 14.7 mm
Pcb
R26_R_0603_1608Metric_5D888A9A
R25_R_0603_1608Metric_5D888A8A
R24_R_0603_1608Metric_5D888A7A
R23_R_0603_1608Metric_5D888A6A
R22_R_0603_1608Metric_5D888A5A
R21_R_0603_1608Metric_5D888A4A
Q5_SOT_23_5D888A36
D16_D_SOT_23_5D888A1D
D15_D_SOT_23_5D888A04
C11_C_0805_2012Metric_5D8889F4
C10_C_0805_2012Metric_5D8889E4
C9_C_0805_2012Metric_5D8889D4
C8_C_0805_2012Metric_5D8889C4
C6_C_0805_2012Metric_5D8889B4
D6_D_SMA_5D88899D
Q2_SOT_23_5D888989
Q1_SOT_23_5D888975
Y2_Crystal_SMD_3225-4Pin_3.2x2.5mm_HandSoldering_5D888962
U8_SOT_23_5_5D88894E
U6_SOIC_16_39x99mm_P127mm_5D88892A
U5_LGA_14_3x5mm_P08mm_LayoutBorder1x6y_5D888909
U4_TQFP_64_14x14mm_P08mm_5D8888B3
R20_R_0603_1608Metric_5D8888A3
R19_R_0603_1608Metric_5D888893
R18_R_0603_1608Metric_5D888883
R17_R_0603_1608Metric_5D888873
R10_R_0603_1608Metric_5D888863
R9_R_0603_1608Metric_5D888853
J8_JST_B4B_XH_A_5D888829
U9_TSOT_23_5_5D888814
D5_D_SMA_5D8887FD
F1_R_1206_3216Metric_5D8887D9
D1_D_SMA_5D8887C2
R6_R_0603_1608Metric_5D888777
D9_LED_D3.0mm_Horizontal_O1.27mm_Z2.0mm_5D888760
D8_LED_D3.0mm_Horizontal_O1.27mm_Z2.0mm_5D888749
D7_LED_D3.0mm_Horizontal_O1.27mm_Z2.0mm_5D888732
D10_LED_D3.0mm_Horizontal_O1.27mm_Z2.0mm_5D88871B
C2_C_0805_2012Metric_5D88870B
D2_D_SOD_323_5D8886F4
R8_R_0603_1608Metric_5D888300
R7_R_0603_1608Metric_5D8882F0
R5_R_0603_1608Metric_5D8882E0
R4_R_0603_1608Metric_5D8882D0
R3_R_Array_Convex_4x0603_5D8882BA
R1_R_0603_1608Metric_5D8882AA
J3_JST_B3B_XH_A_5D888281
D4_LED_0805_2012Metric_5D88826F
D3_D_SMA_5D888258
C3_CP_Elec_8x105_5D888231
C1_C_Radial_D80mm_H115mm_P350mm_5D888228
SW1_SW_DIP_SPSTx08_Slide_Omron_A6H_8101_W615mm_P127mm_5D8881B7
J1_PinHeader_2x03_P254mm_Vertical_5D88819C
D11_D_SOD_323_5D888175
D14_SOT_23_5D888161
U2_TO_263_5_TabPin3_5D888126
J4_USB_Mini-B_Lumberg_2486_01_Horizontal_5D8880E0
C4_C_0603_1608Metric_5D8880D0
R2_R_0603_1608Metric_5D8880C0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

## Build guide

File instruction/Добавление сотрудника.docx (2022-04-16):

- Добавление сотрудника

Для добавления сотрудника следует нажать кнопку “+” на панели “Персонал”, как показано на рисунке ниже

После этого на экране появится диалог “Новый сотрудник”

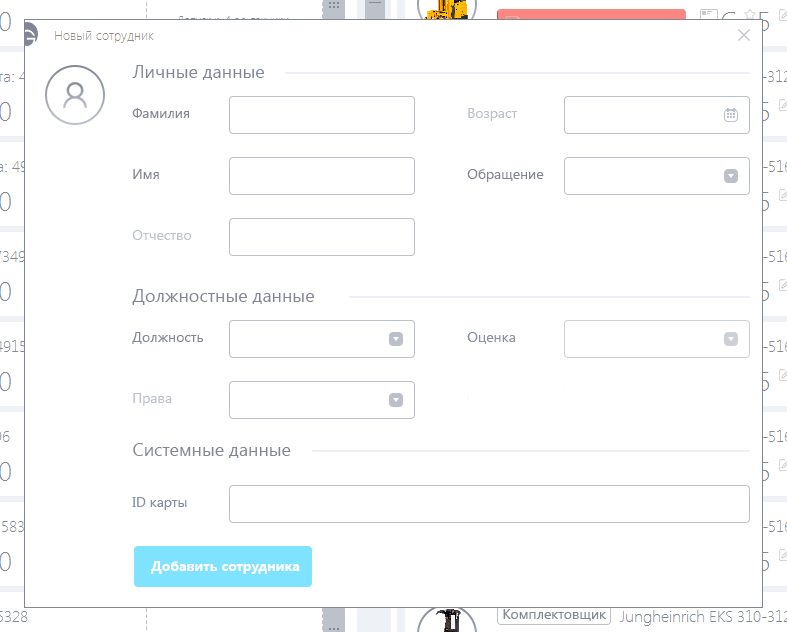
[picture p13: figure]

Поля, выделенные тёмным цветом, являются обязательными для заполнения!

Описание полей:

Фамилия Имя Отчество – вводятся фамилия имя и отчество сотрудника, которые в дальнейшем будут отображаться в списке персонала

Возраст – указывается дата рождения сотрудника

Обращение – из списка требуется выбрать пол сотрудника

Должность – в списке имеется 5 вариантов, которые требуются просто для индикации и фильтрации персонала в общем списке. Следует обратить внимание на элемент в списке “Мастер”, если у сотрудника указана данная должность, то данная карта имеет возможность запустить любую технику по умолчанию и сбросить аварию по удару на ней.

Оценка – субъективная оценка сотрудника, которую даёт руководитель подразделения по своему усмотрению.

Права – требуется выбрать из списка категорию прав, допуска к технике, сотрудника

ID карты – цифровой код карты сотрудника. Для его получения требуется воспользоваться дополнительной утилитой, из папки клиента.

После ввода всех данных в поля следует нажать кнопку “Добавить сотрудника”, если данные заполнены, верно, то информация добавится в базу данных и обновится в клиентском приложении.

ВНИМАНИЕ! Следует учитывать, что в поля запрещено вводить следующие зарезервированные символы ! @ # $ & :

Утилита для считывания RFID-карт

В папке с клиентским приложением имеется программа “Считывание карт.exe”.

После запуска программы появится окно как на рисунке. Теперь требуется вставить считыватель в любой USB-порт и установить драйвера для него, которые так же можно найти в папке с клиентом 067b_x32_x64_win_v7810_manual

После установки драйверов в системе появится виртуальный com-порт:

После этого окно программы для считывания должно стать зелёным:

Теперь если к считывателю приложить карту сотрудника, то в поле появится RFID карты в десятичном виде, который требуется скопировать в поле “ID карты”, или ввести вручную числовой код.

- Добавление техники

Для добавления техники следует нажать “+” на панели техники, как показано на рисунке ниже

После чего на экране появится диалог “Новый борт”

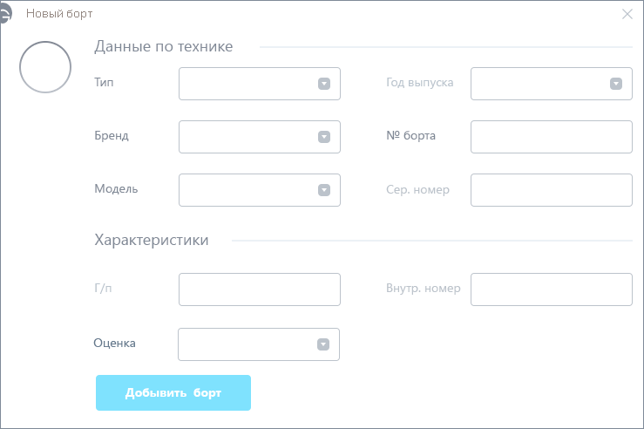
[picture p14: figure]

Поля, выделенные тёмным цветом, являются обязательными для заполнения!

Описание полей:

Тип: требуется выбрать из списка тип используемой техники

Бренд: требуется выбрать из списка бренд используемой техники

Модель: требуется выбрать из списка модель используемой техники

Год выпуска: требуется выбрать из списка год выпуска от 2010г до текущего

№ борта: ID платы устройства, которая установлена на данной технике

Сер. номер: серийный номер данного борта, указанный на шилде

Г/п: грузоподъёмность борта

Внутр. номер: внутренний бортовой номер борта

Оценка: оценка состояния борта

После заполнения всех полей требуется нажать кнопку “Добавить борт”, и система перейдёт обратно к списку персонала и техники.

- Добавление и удаление разрешений на пользование техникой

Для того что бы дать определённому сотруднику права на управление

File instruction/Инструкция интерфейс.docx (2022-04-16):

Клиентское приложение системы “Устройство бесключевого доступа”

Введение

Клиентское приложение предоставляет удалённый доступ к удобному механизму управления и получения различной статистики по работе склада.

- Данное приложение обладает следующими основными функциями:
- Различный учёт и контроль над техникой
- Различный учёт и контроль надо зарегистрированным персоналом
- Управление правами доступа сотрудника к определённой технике
- Управление правами доступа к данной системе и разграничение функционала
- Удобную навигацию по спискам персонала и техники в больших складах
- Выгрузку в формате xlsx для дальнейшего удобного анализа данных в excel’e
- Добавление различных комментариев к сотрудникам и технике

Обзор общего интерфейса приложения

Интерфейс приложения визуально можно разделить на четыре части, как показано на рисунке 1


Рисунок 1. Интерфейс клинтского приложения

1. Панль управления

Содержит несколько элементов управления

| Обновить списки техники и персонала
| Панель по статистике по ударов. Нет новых ударов
| Панель по статистике по ударов. Совершены новые удары
| Панель управления учётными записями
| Свернуть приложение
| Закрыть приложение

2. Панель общей статистики по складу

Содержит сводную статистику по персоналу и технике, а именно количество персонала и техники выведеных и количество не рабочих сотрудников и техники в простое за текущую смену. Имеющееся поле для ввода преднозначено для удобной навигации по спискам персонала и техники. Для персонала поиск и фильтрация идёт по имени, фамилии, отчеству и номеру личной карты. Для техники поиск и фильтрация предлагается по серийному номеру и номеру борта. При вводе в данных полях текста происходит поиск и динамическая фильтрация списков, если найдено хотя бы одно совпадение.

Также имеются некоторые элементы управления

| Сводная эффективность за смену по результатам работы и простоя. Меняет цвет в диапозоне красного и зелёного в зависимости от показателя эффективности
| Дополнительная фильтрация персонала и техники
| Панель по статистике по ударов. Совершены новые удары

3. Панель управления персоналом

Более подробное изображение одного элемента данной панели приведено на рисунке 2

Рисунок 2. Сводная карточка сотрудника на панели управления персоналом

В данном элементе управления присутствует вся необходимая информация по конкретному сотруднику

Фамили, имя, возраст, а так же номер личной карты сотрудника. Расшифровка некоторых пиктограмм:

| Фотография сотрудника. При одиночном щелчке на фотографию сотрудника устанавливается или снимается пометка в форме влажка, которую можно использовать для более удобной навигации и обозначения сотрудника
| Должность сотрудника
| Эффективность данного сотрудника в рамках текущего месяца
| Категория водительских прав сотрудника в рамкох данного склада
| Оценка компетентности данного сотрудника
| Количество заметок по данному сотруднику
| Данное поле содержит информацию о количестве технике к которой допущен сотрудник. Также имеется динамическое отображение информации о борте которым в данный момент управляет сотрудник. Если поле является красным, то сотрудник пытается запустить борт к которому не допущен, если зелёный, то сотрудник запустил борт к которому допущен. Белое, пустое поле говорит о простое сотрудника. Одиночное нажатие на поле вызывает список привязок

Двойное нажатие на данном элементе вызывает полную информацию о сотруднике с возможностью редактирования, при условии, что имеются права доступа к данной функции.

4. Панель управления техникой

Более подробное изображение одного элемента данной панели приведено на рисунке 3

Рисунок 3. Сводная карточка борта на панели управления техникой

В данном элементе управления присутствует вся необходимая информация по конкретному борту

Бренд, модель и внутренний номер борта. Расшифровка некоторых пиктограмм:

| Фотография борта. При одиночном щелчке на фотографию борта устанавливается или снимается пометка в форме влажка, которую можно использовать для более удобной навигации и обозначения борта
| Тип техники
| Эффективность данного борта в рамках текущего месяца
| Категория водительских прав, необходимых для управления данным бортом, в рамкох данного склада
| Оценка состояния данного борта
| Количество заметок по данному борту
| Данное поле содержит информацию о количестве персонала который допущен к управлению данным бортом. Также имеется динамическое отображение информации о сотруднике который в данный момент управляет бортом. Если поле является красным, то сотрудник пытается запустить борт к которому не допущен, если зелёный, то сотрудник запустил борт к которому допущен. Белое, пустое поле говорит о простое борта. Одиночное нажатие на поле вызывает список привязок

Двойное нажатие на данном элементе вызывает полную информацию о борте с возможностью редактирования, при условии, что имеются права доступа к данной функции.

5. Управление персоналом

Добавление нового сотрудника

Для добавления нового сотрудника следует вызвать диалог заполнения новой карточки на сотрудника, нажатием пиктограммы . После чего на экране появится пустая карточка сотрудника как на рисунке 4

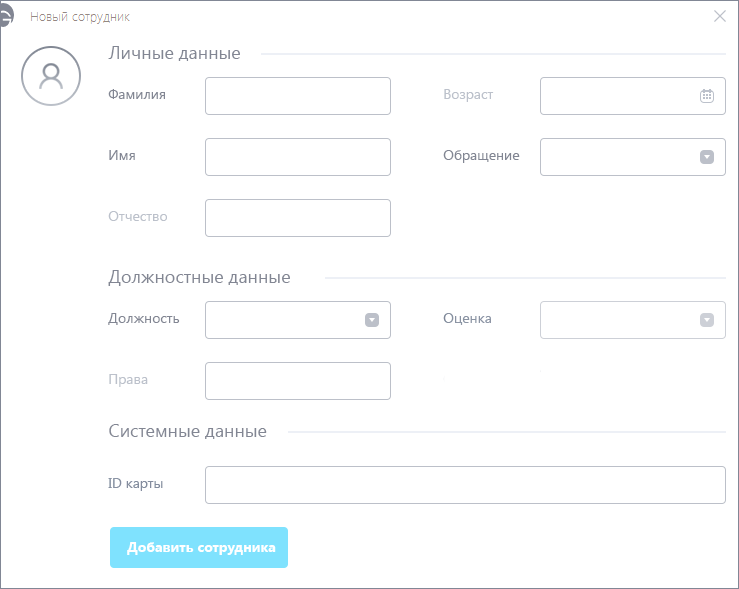
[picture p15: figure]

Рисунок 4. Карточка добавления нового сотрудника

Рассмотрим подробнее данный диалог. Мы видим следующие поля и выпадающие списки

Фамилия Имя Отчество. Фамилия имя и отчество нового сотрудника;

Возраст. Возможность выбора даты рождения сотрудника;

Обращение. Пол сотрудника (Муж или Жен);

Должность. Предлагается выбрать должность сотрудника из списка (Мастер, оператор, механик, аккумуляторщик, кладовщик, комплектовщик);

Оценка. Оценка компетентности сотрудника по пятибалльной шкале;

Права. Категория или номер внутренних прав сотрудника;

ID карты. Номер личной карты сотрудника. О получении номера карты будет рассказано дальше.

Поля название, которых, выделено более контрастным цветом, являются обязательными для заполнения. Если данные поля не заполнены либо заполнены не корректно, то при нажатии кнопки “Добавить сотрудника”, система выдаст предупреждающее уведомление и окрасит конфликтное поле в красный цвет.

После успешного добавления сотрудника, сводная карточка автоматически появится в панели управления сотрудником.

Редактирование карточки сотрудника

Для редактирования карты сотрудника, следует дважды щёлкнуть на любом пустом месте элемента панели управления персоналом, после чего всплывёт диалог редактирования, который схож по функционалу с диалогом добавления сотрудника, за исключением названия диалога и трёх кнопок, сохранить карту, удалить карту и заметки. Названия кнопок говорит само за себя.

Поиск и фильтрация персонала

При большом штате зарегистрированных в системе сотрудников, предусмотрен алгоритм поиска и фильтрации. На панели общей статистики в разделе персонал, можно найти поле для ввода и пиктограмму фильтра . При нажатии на фильтр, предлагается диалог настройки фильтрации, как показано на рисунке 5.

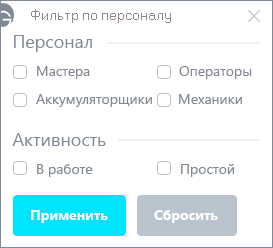
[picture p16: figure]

Рисунок 5. Фильтр по персоналу

Предполагается, что пользователь выберет интересующую должность сотрудника и/или активность сотрудника в данный момент. После необходимой настройки фильтра и нажатия кнопки “Применить”, диалог закроется и список персонала отфильтруется по правилам настройки фильтра. К примеру, требуется вывести всех операторов и механиков, которые в данный момент управляют техникой, тогда следует поставить соответствующие галочки (Операторы, механики, в работе) и нажать “Применить”, и список сформируется соответственно.

Также имеется возможность ручного поиска, с помощью текстового поля, показанного на рисунке 6

Рисунок 6. Текстовое поля для поиска персонала

Ручной ввод в данном поле позволяет искать по совпадению в полях карточки сотрудника и формировать требуемый список персонала

Добавление разрешений на управление техникой

Для добавления разрешения на управление техникой требуется создать связь между сотрудником и бортом, следующим образом:

Зажать левую кнопку мыши на данном поле

После взятия карточки сотрудника данные поля в панели управления техникой, подсветятся зелёным или красным. Зелёное поле сигнализируют о том, что к данной карте борта можно добавить сотрудника, красное поле сигнализирует о том, что данный сотрудник уже добавлен к данному борту

Далее следует тянуть карточку сотрудника в панель управления техникой и навести, не отпуская, на требуемый борт, если при наведении появится красное обрамление карточки борта, то можно отпускать левую кнопку мыши, после чего карта бора моргнёт несколько раз зелёным цветом, что означает успешное создание связи между сотрудником и бортом

После добавления связи счётчик допусков на карточке персонала и техники возрастёт на один.

Удаление разрешений на управление техникой

Для удаления связи между техникой и персоналом, следует вызвать меню привязок, одинарным нажатием на данную область . Список привязок показан на рисунке 7

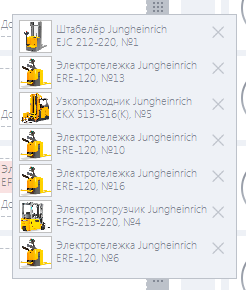
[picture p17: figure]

Рисунок 7. Список привязок техники к сотруднику

Если данный список выходит за рамки экрана, то при нажатии клавиши ctrl на клавиатуре, можно его перетягивать, мышью, вверх или вниз.

Для удаления привязки следует нажать напротив соответствующего борта и подтвердить удаление. Если требуется удалить большое количество привязок, следует нажать напротив соответствующего борта с зажатой клавишей shift на клавиатуре, тогда удаление произойдёт без подтверждения, что сэкономит время.

Добавление заметок о персонале

Для добавления заметки следует нажать пиктограмму заметки в карточке сотрудника, после чего появится диалог “Заметки по оператору”, как показано на рисунке 8.

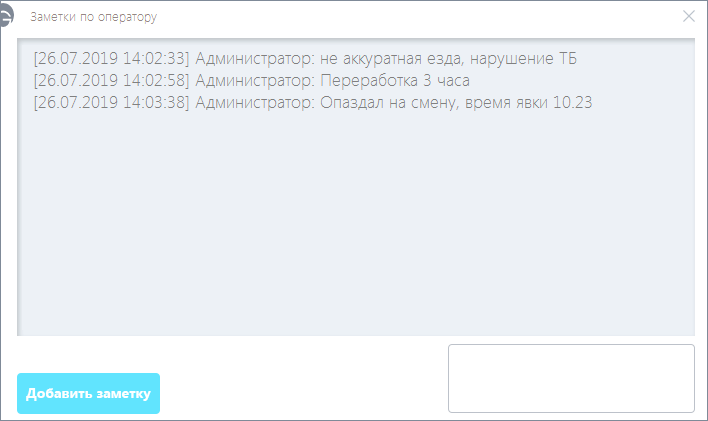
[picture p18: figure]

Рисунок 8. Заметки

Для добавления заметки, следует в текстовом поле, напечатать требуемый текст и нажать кнопку “Добавить заметку”, после чего в списке автоматически появится запись о заметки, дата, время создания и имя пользователя, который добавил данную заметку.

Редактирование и удаление заметки

Для редактирования заметки требуется двойным нажатием выбрать заметку в списке, после чего текст заметки автоматически скопируются в поле для ввода и отобразятся две дополнительные кнопки “Сохранить” и “Удалить”. Если изменить текст заметки в поле для ввода и нажать “Сохранить”, то заметка сохранится в списке с новым текстом, если нажать “Удалить”, то заметка удалится из списка.

Примечание! Возможность редактирования заметки сохраняется в течение 48 часов после её создания, по истечении данного времени удаление и редактирование данной заметки не возможно!

Статистика по персоналу

Для просмотра статистики по определённому сотруднику, достаточно нажать на график эффективности, в карте данного сотрудника . Открывается журнал по оператору, как показано на рисунке 9.

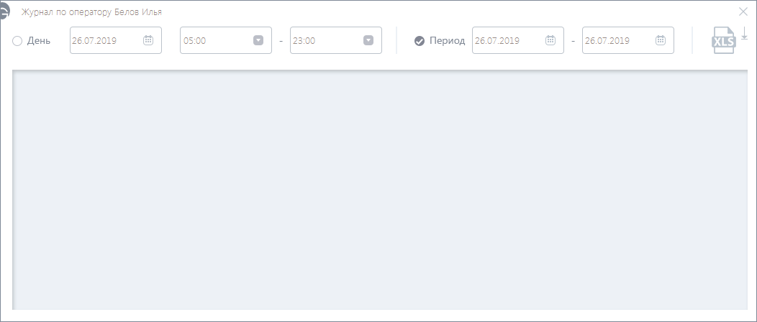
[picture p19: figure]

Рисунок 9. Журнал статистики по оператору

Для получения статистики следует настроить интервал, который следует выгрузить.

При выборе опции “День”, требуется указать дату, за которую будет совершена выгрузка и интервал времени

При выборе опции “Период” требуется указать интервал дат, между которыми будет совершена выгрузка

После настройки интервала следует нажать кнопку выгрузки . Выгрузка из базы может занять некоторое время, в зависимости от выбранного интервала, имейте терпение! После удачной выгрузки в списке ниже появится перечень действий, которые были совершены сотрудником за указанный интервал времени. Или система сообщит о том, что за данный интервал статистики нет! Для более удобного представления информации, данные можно передать в excel, для этого требуется нажать кнопку . Выгрузка в excel может потребовать некоторого времени, процесс выгрузки будет виден в верхнем правом углу журнала. После завершения выгрузки автоматически откроется excel со сформированной таблицей.

6. Управление техникой

Добавление нового борта

Для добавления нового борта следует вызвать диалог заполнения новой карточки для борта, нажатием пиктограммы . После чего на экране появится пустая карточка борта как на рисунке 10

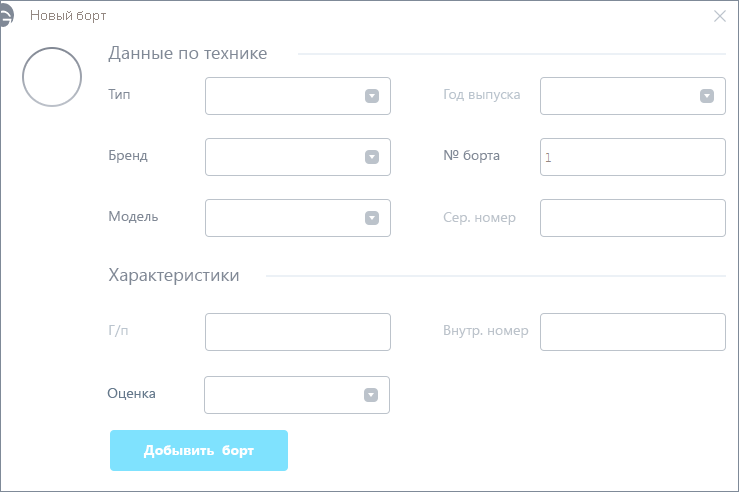
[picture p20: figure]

Рисунок 10. Карточка добавления нового борта

Рассмотрим подробнее данный диалог. Мы видим следующие поля и выпадающие списки

Тип. Следует выбрать тип техники (электротележка, электропогрузчик, штабелёр, ричтрак, комплектовщик или узкопроходник);

Бренд. Требуется выбрать бренд техники (Jung, Still, Linde, BT);

Модель. Данный список формируется на основании выбора сделанного в предыдущих списках;

Год выпуска. Требуется выбрать год выпуска борта из календаря;

№ борта. Идентификационный номер устройства установленного на борт;

Серийный номер. Заводской серийный номер борта;

Г/п. Грузоподъёмность борта в тоннах.

Внутренний номер. Внутренний номер борта, указанный на корпусе.

Оценка. Оценка состояния техники

Поля название, которых, выделено более контрастным цветом, являются обязательными для заполнения. Если данные поля не заполнены либо заполнены не корректно, то при нажатии кнопки “Добавить борт”, система выдаст предупреждающее уведомление и окрасит конфликтное поле в красный цвет.

После успешного добавления борта, сводная карточка автоматически появится в панели управления техникой.

Редактирование карточки борта

Для редактирования карты борта, следует дважды щёлкнуть на любом пустом месте элемента панели управления техникой, после чего всплывёт диалог редактирования, который схож по функционалу с диалогом добавления борта, за исключением названия диалога и трёх кнопок, сохранить карту, удалить карту и заметки. Названия кнопок говорит само за себя.

Поиск и фильтрация техники

При большом штате зарегистрированных в системе бортов, предусмотрен алгоритм поиска и фильтрации. На панели общей статистики в разделе Техника, можно найти поле для ввода и пиктограмму фильтра . При нажатии на фильтр, предлагается диалог настройки фильтрации, как показано на рисунке 11.

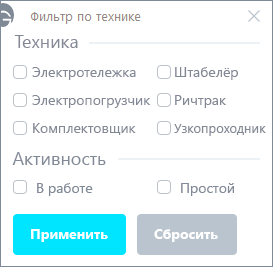
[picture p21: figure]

Рисунок 11. Фильтр по технике

Предполагается, что пользователь выберет интересующий тип техники и/или активность борта в данный момент. После необходимой настройки фильтра и нажатия кнопки “Применить”, диалог закроется и список техники отфильтруется по правилам настройки фильтра. К примеру, требуется вывести все электротележки, которые в данный момент запущены, тогда следует поставить соответствующие галочки (Электротележка и в работе) и нажать “Применить”, и список сформируется соответственно.

Также имеется возможность ручного поиска, с помощью текстового поля, показанного на рисунке 12

Рисунок 12. Текстовое поля для поиска техники

Ручной ввод в данном поле позволяет искать по совпадению в полях карточки борта и формировать требуемый список техники

Добавление разрешений на управление техникой

Для добавления разрешения на управление техникой требуется создать связь между сотрудником и бортом, следующим образом:

Зажать левую кнопку мыши на данном поле

После взятия карточки борта данные поля в панели управления персоналом, подсветятся зелёным или красным. Зелёное поле сигнализируют о том, что к данной карте сотрудника можно добавить борт, красное поле сигнализирует о том, что данный борт уже добавлен к данному сотруднику

Далее следует тянуть карточку борта в панель управления персоналом и навести, не отпуская, на требуемого сотрудника, если при наведении появится красное обрамление карточки сотрудника, то можно отпускать левую кнопку мыши, после чего карта сотрудника моргнёт несколько раз зелёным цветом, что означает успешное создание связи между сотрудником и бортом

После добавления связи счётчик допусков на карточке персонала и техники возрастёт на один.

Удаление разрешений на управление техникой

Для удаления связи между техникой и персоналом, следует вызвать меню привязок, одинарным нажатием на данную область . Список привязок показан на рисунке 13

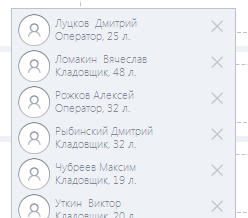
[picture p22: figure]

Рисунок 13. Список привязок техники к сотруднику

Если данный список выходит за рамки экрана, то при нажатии клавиши ctrl на клавиатуре, можно его перетягивать, мышью, вверх или вниз.

Для удаления привязки следует нажать напротив соответствующего сотрудника и подтвердить удаление. Если требуется удалить большое количество привязок, следует нажать напротив соответствующего сотрудника с зажатой клавишей shift на клавиатуре, тогда удаление произойдёт без подтверждения, что сэкономит время.

Добавление заметок для борта

Для добавления заметки следует нажать пиктограмму заметки в карточке борта, после чего появится диалог “Заметки по борту”, как показано на рисунке 14.

Рисунок 14. Заметки

Для добавления заметки, следует в текстовом поле, напечатать требуемый текст и нажать кнопку “Добавить заметку”, после чего в списке автоматически появится запись о заметки, дата, время создания и имя пользователя, который добавил данную заметку.

Редактирование и удаление заметки

Для редактирования заметки требуется двойным нажатием выбрать заметку в списке, после чего текст заметки автоматически скопируются в поле для ввода и отобразятся две дополнительные кнопки “Сохранить” и “Удалить”. Если изменить текст заметки в поле для ввода и нажать “Сохранить”, то заметка сохранится в списке с новым текстом, если нажать “Удалить”, то заметка удалится из списка.

Примечание! Возможность редактирования заметки сохраняется в течение 48 часов после её создания, по истечении данного времени удаление и редактирование данной заметки не возможно!

Статистика по технике

Для просмотра статистики по определённому борту, достаточно нажать на график эффективности, в карте данного борта . Открывается журнал по борту, как показано на рисунке 15.

Рисунок 15. Журнал статистики по борту

Для получения статистики следует настроить интервал, который следует выгрузить.

При выборе опции “День”, требуется указать дату, за которую будет совершена выгрузка и интервал времени

При выборе опции “Период” требуется указать интервал дат, между которыми будет совершена выгрузка

После настройки интервала следует нажать кнопку выгрузки . Выгрузка из базы может занять некоторое время, в зависимости от выбранного интервала, имейте терпение! После удачной выгрузки в списке ниже появится перечень действий, которые были совершены персоналом над бортом за указанный интервал времени. Или система сообщит о том, что за данный интервал статистики нет! Для более удобного представления информации, данные можно передать в excel, для этого требуется нажать кнопку . Выгрузка в excel может потребовать некоторого времени, процесс выгрузки будет виден в верхнем правом углу журнала. После завершения выгрузки автоматически откроется excel со сформированной таблицей.

Статистика по ударам

Журнал статистики по ударам выглядит так же как журнал статистики по персоналу и технике, и предоставляет тот же функционал.

Для открытия данного журнала, требуется нажать на пиктограмму или , красная точка сигнализирует о новых не просмотренных ударах.

Мастер карты

Мастер карта позволяет запустить любую технику, зарегистрированную в системе. Так же позволяет сбрасывать аварии и удары борта.

Для создания мастер карты следует добавить сотрудника, вышеуказанным способом, и поменять его должность на “Мастер”.

Примечание! Всего мастер карты в системе может быть 5 штук!

Утилита для считывания RFID-карт

В папке с клиентским приложением имеется программа “Считывание карт.exe”.

После запуска программы появится окно как на рисунке 16. Теперь требуется вставить считыватель в любой USB- порт и установить драйвера для него, которые так же можно найти в папке с клиентом 067b_x32_x64_win_v7810_manual

Рисунок 16. Общий вид и иконка программы для считывания карт

После установки драйверов в системе появится виртуальный com-порт:

После этого окно программы для считывания должно стать зелёным как на рисунке 17

Рисунок 17. Общий вид программы для считывания карт с подключённым считывателем

Теперь если к считывателю приложить карту сотрудника, то в поле появится RFID карта в десятичном виде, который требуется скопировать в поле “ID карты”, или ввести вручную числовой код.

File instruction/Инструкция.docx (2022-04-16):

Инструкция по работе с системой бес ключевого доступа

ВВЕДЕНИЕ

Система бес ключевого доступа (СБД) состоит из нескольких отдельных частей:

- Сервер обработки телеметрии и базы данных
- Устройство бес ключевого доступа (УБД)
- Клиентское приложение
1. Сервер обработки телеметрии и база данных

Сервер обеспечивает связь всех частей системы между собой и осуществляет обмен информации между ними. На рисунке 1 приведена структурная схема всей системы в целом.

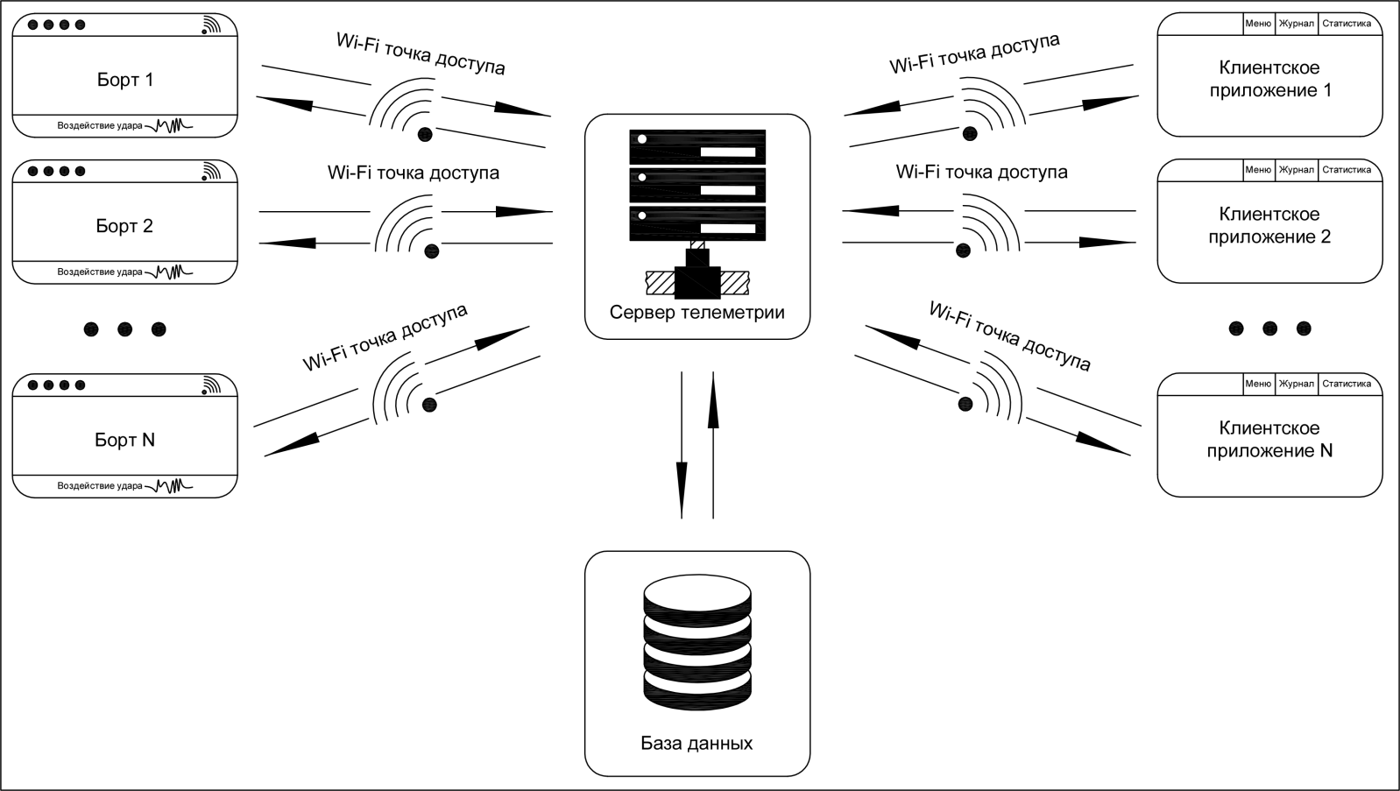
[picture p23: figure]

Рисунок 1. Структурная схема системы бес ключевого доступа

Для работы СБД требуется наличие стабильной Wi-Fi сети по всей территории предполагаемого действия системы, в противном случае стабильная работа и сбор статистики не может быть гарантирован. Все части СБД должны находиться в одной подсети.

Сервер доступен, для бортов и клиентских приложений, по ранее настроенному IP-адресу и порту 3333. Ограничения внутри данной подсети могут привести к нестабильной работе СБД в целом.

УБД и клиентские приложения устанавливают между сервером TCP-соединение, по которому и обмениваются между собой данными. Если УБД не отвечает на 6 запросов сервера, то TCP соединение автоматически закрывается.

Обмен данными между сервером и УБД начинается сразу после создания TCP соединения. Если сервер одобрил запрос на соединение, то УБД присылает стартовую строку, которая содержит информацию об УБД (борт), которое запросило соединение, а именно ID-устройства, текущая RFID-карта и состояние флага удара.

Если текущая RFID-карта отлична от нуля, сервер пытается найти разрешение данной карты на включение данного борта, если разрешение найдено, то в базу данных (таблица “Tele”) записывается информация о времени открытия сессии, если же в базе данных имеется не закрытая сессия поданному борту, то продолжается подсчёт времени для него.

В ответ на стартовую строку сервер отсылает УБД пакет с разрешёнными RFID_USER-картами и RFID_MASTER-картами, который состоит из строки инициализации “RFID_List_fixed_len_blabla”, 160 байт со списком RFID-карт и CRC-суммы.

Каждая RFID-карта состоит из 4 байт, т.е. присланные 160 байт это 40 RFID-карт. Карты с первой по тридцать пятую, это карты-пользователей. Карты с тридцать шестой по сороковую, это мастер-карты.

CRC – это контрольная сумма пакета, которая высчитывается путём сложения первых четырёх бит каждой RFID-карты. Максимальная сумма от такого сложения не будет превышать 600, поэтому CRС, это два байта в пакете.

Более наглядно пакеты обмена УБД с сервером приведены на рисунке 2.

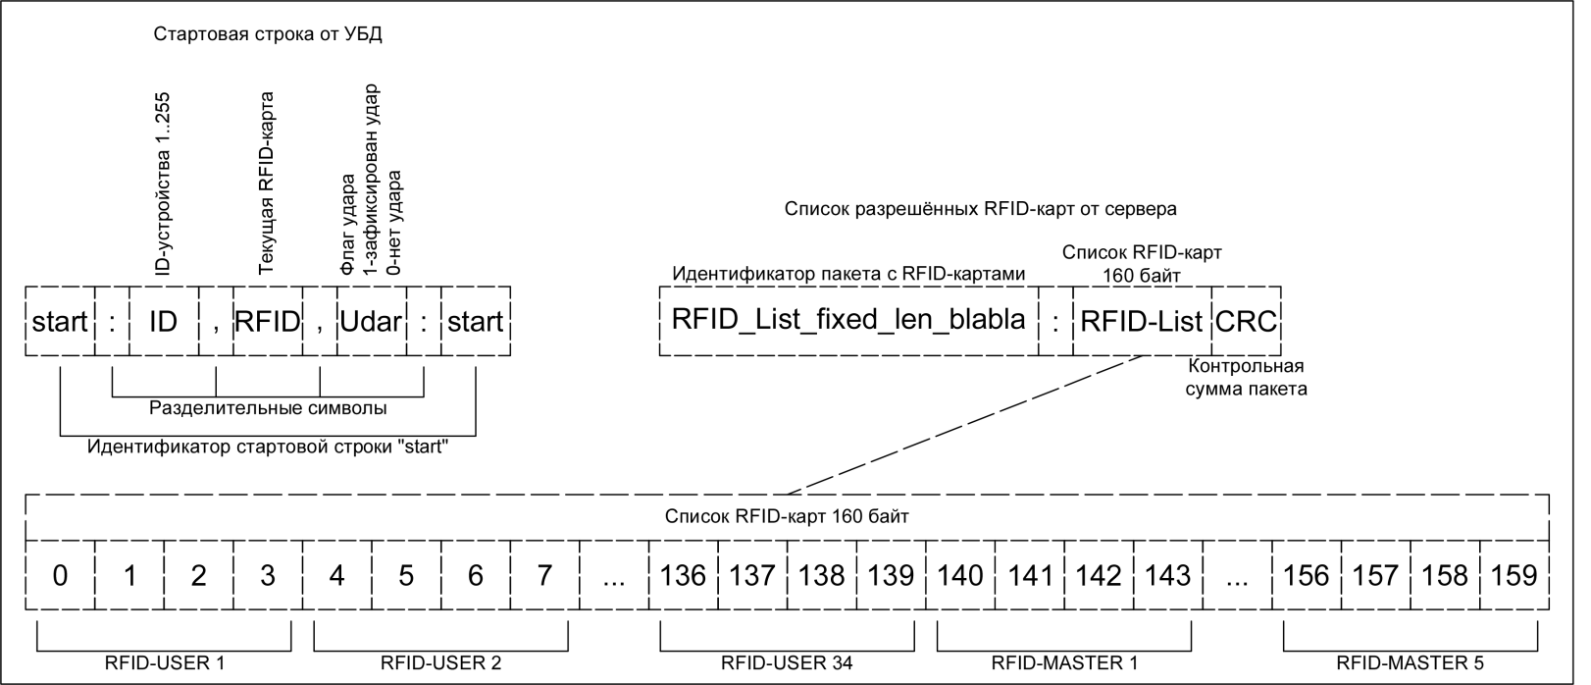
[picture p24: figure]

Рисунок 2. Структура пакетов при обмене данными между УБД и сервером

Обмен данными между клиентским приложением и сервером позволяет клиентскому приложению (клиент) получать данные о состоянии системы, пользователей, сотрудников, техники и управлять ими.

Приём данных.

Сервер обязан предоставлять клиенту информацию о списках сотрудников, техники, разрешений на работу с техникой, информацию о работающей технике и сотрудниках, статистику по ударам, по общей эффективности техники и рабочих. Так же сервер умеет обрабатывать команды от клиента, такие как удаление\добавление техники, персонала, разрешений на работу с техникой, заметок о персонале или технике. Сервер уведомляет клиента о произошедших ударах техники и умеет различать прочитанные уведомления. Пакеты обмена и их структура слишком большая и обширная для данной инструкции.

База данных на данный момент состоит из нескольких таблиц:

- Notepad
- Personal
- Profile
- Razreshenia
- Tehnika
- Tele
- Udar

Notepad, таблица для хранения заметок о персонале и технике, состоит из следующих полей:

- Date – поле для хранения даты и времени добавления заметки в формате “dd.mm.yyyy hh:mm:ss”
- Type – поле хранит пометку о ком заметка, P=персонал, T=техника
- UID – уникальный идентификатор сотрудника или борта (зависит от поля Type)
- Text – текст заметки
- WhuIs – информация об авторе заметки
- ID – порядковый номер заметки

Personal, таблица для хранения информации о персонале, состоит из следующих полей:

- Surname – фамилия сотрудника
- Name – имя сотрудника
- Lastname – отчество сотрудника
- Prof – должность сотрудника (мастер, оператор, механик, аккумуляторщик и другое)
- RFID – RFID-карта сотрудника в 4 байтовом формате
- Data – дата рождения сотрудника
- Ocenka – оценка сотрудника (может быть 1..5)
- UID – уникальный номер сотрудника
- Prava – категория брав сотрудника (может быть n\a, B, C)
- Sex – пол сотрудника (может быть Муж, Жен)

Profile, таблица для хранения информации о пользователях, состоит из следующих полей:

- Login – учётная запись для входа в систему
- Pass – пароль для входа в систему
- FIO – фамилия имя отчество пользователя
- Prava – права доступа к данным (может быть Admin, Master и User)
- Prochee – дополнительная информация о пользователе

Razreshenia, таблица для хранения разрешений на использование техники, состоит из следующих полей:

- ID – UID техники
- RFID – UID сотрудника

Tehnika, таблица для хранения информации о технике, состоит из следующих полей:

- Type – тип техники
- Brend – бренд техники
- Model – модель техники
- Gp – максимальная грузоподъёмность
- Vp – максимальная высота подъёма
- God – год выпуска
- GNomer – государственный номер борта
- Ocenka – техническое состояние техники (может быть 1..5)
- ID – внутренний номер техники (может быть 1..255)
- UID – уникальный идентификатор техники
- Prava – требуемые права для управления техникой

Tele, таблица для хранения телеметрии на технику, состоит из следующих полей:

- Date_n – дата открытия сессии
- Time_n – время открытия сессии
- Date_k – дата окончания сессии
- Time_k – время окончания сессии
- UID_T – UID техники
- UID_P – UID сотрудника управляющим бортом
- Status – время в секундах, разница между окончанием сессии и началом сессии

Udar, таблица для хранения информации о совершённых ударах

- Data – дата удара
- Time – время удара
- UIDP – UID сотрудника совершившего удар
- UIDT – UID борта, который прислал удар
- Sila – флаг просмотренного сообщения об ударе (1=не просмотрено, 0=просмотрено)

База данных должна располагаться каталогом выше от пути расположения файлов сервера, например:

Каталог сервера: “C:\Program Files\ServerKS\Bin\”

Расположение базы данных: “C:\Program Files\ServerKS\”

2. Устройство бес ключевого доступа

УБД состоит из нескольких функциональных частей:

- Управляющего контроллера
- Wi-Fi модуль
- Модуль удара
- Модуль подстройки порога удара
- Модуль индикации
- Модуль реле
- RFID считыватель
- Связь с ПК TTL
- Разъём SPI для программирования контроллера

Запуск и отладка УБД

На данный момент функционал по удалённой настройки УБД не реализован, поэтому настройку следует производить с помощью прошивки контроллера.

Для стабильного запуска контроллера требуется настроить несколько переменных и констант в прошивке, а именно в файле Vars (переменные). Далее последуют имена переменных и констант с описанием и рекомендациям по настройке:

- Ap_name – Имя точки доступа. Следует ввести имя точки доступа (Wi-Fi сети), которую предоставил системный администратор. ВНИМАНИЕ: Чувствительно к регистру и вводится после знака равно в кавычках!
- Pass_ap - пароль для точки доступа. ВНИМАНИЕ: Чувствительно к регистру и вводится после знака равно в кавычках!
- Server_ip(1) – массив для IP-адреса сервера СБД. Первая цифра. Без точки
- Server_ip(2) – массив для IP-адреса сервера СБД. Вторая цифра. Без точки
- Server_ip(3) – массив для IP-адреса сервера СБД. Третья цифра. Без точки
- Server_ip(4) – массив для IP-адреса сервера СБД. Четвёртая цифра. Без точки
- Server_port – порт для подключения к серверу УБД
- Id – ID-устройства, обычно это внутренний номер борта. ВНИМАНИЕ: не должен повторяться!

Пример настройки:

Ap_name = “NETGEAR”

Pass_ap = ”111222333444”

Server_ip(1) = 192

Server_ip(2) = 168

Server_ip(3) = 0

Server_ip(4) = 77

Server_port = 3333

Id = 5

После прошивки устройства требуется настроить порог удара. Порог удара, это сила удара, при которой УБД встанет в режим аварии. Для этого на устройстве присутствует “Модуль подстройки порога удара”. Крестовой отвёрткой вращать построечный резистор (синий квадрат). По часовой стрелке, это уменьшение порога, против часовой стрелки, это увеличение порога удара. Для сохранения изменений требуется зажать кнопку до тех пор, пока не начнёт мигать красный светодиод, после чего отпустить. При фиксации удара больше порогового значения, устройство переходит в режим аварии, в котором включается реле “Черепаха”, отправляется на сервер информация об ударе. Режим аварии сопровождается миганием красного светодиода. Сброс режима аварии возможен только при помощи мастер-карты.

Модуль индикации предназначен для индикации состояния УБД.

Основное назначение светодиодов индикации:

- Красный – индикация подключения к точке доступа. Если устройство получило IP-адрес от точки доступа, то загорается красный светодиод
- Оранжевый – индикация подключения устройства к серверу телеметрии. Если сервер одобрил TCP-соединение с УБД, то загорается оранжевый светодиод
- Зелёный – индикация включённого зажигания. Если приложенная к RFID-считывателю карта найдена в списке разрешённых RFID-карт, то загорается зелёный светодиод
- Синий – индикация того, что RFID-карта приложена к RFID-считывателю.

Второстепенное назначение светодиодов

- Мигание красного светодиода – индикация режима “авария” и включённого реле “Черепаха”
- Мигание зелёного светодиода – индикация того, что к RFID-считывателю приложена мастер-карта
- При зажатой системной кнопки мигание красного светодиода – индикация успешного сохранения нового порога удара в EEPROM

EEPROM УБД хранит в себе настройки необходимые для запуска устройства и список разрешённых RFID-карт. Алгоритм получения и сохранения списка разрешённых RFID-карт, заключается в приёме пакета, который начинается с “RFID_List_fixed_len_blabla”, далее если CRC верен, то присланный список сравнивается с уже имеющемся в EEPROM, если имеется хотя бы одно отличие, то список карт полностью перезаписывается в EEPROM. Если присланный список полностью совпадает со списком в EEPROM, то выводится сообщение в терминал о совпадении списков. Тем самым данный алгоритм, хранения RFID-карт в энергонезависимой памяти устройства, позволяет не дожидаться подключения устройства к серверу и сразу начинать работать после включения питания.

Модуль реле состоит из двух не зависимых реле с двумя сдвоенными перекидными контактами, что позволяет коммутировать нагрузку до 4А.

Первое реле предназначено для включения и отключения зажигания.

Второе реле предназначено для включения и отключения режима “Черепаха”, или для подключения иной нагрузки для индикации данного режима.

На рисунке 3 приведена общая структурная схема УБД.

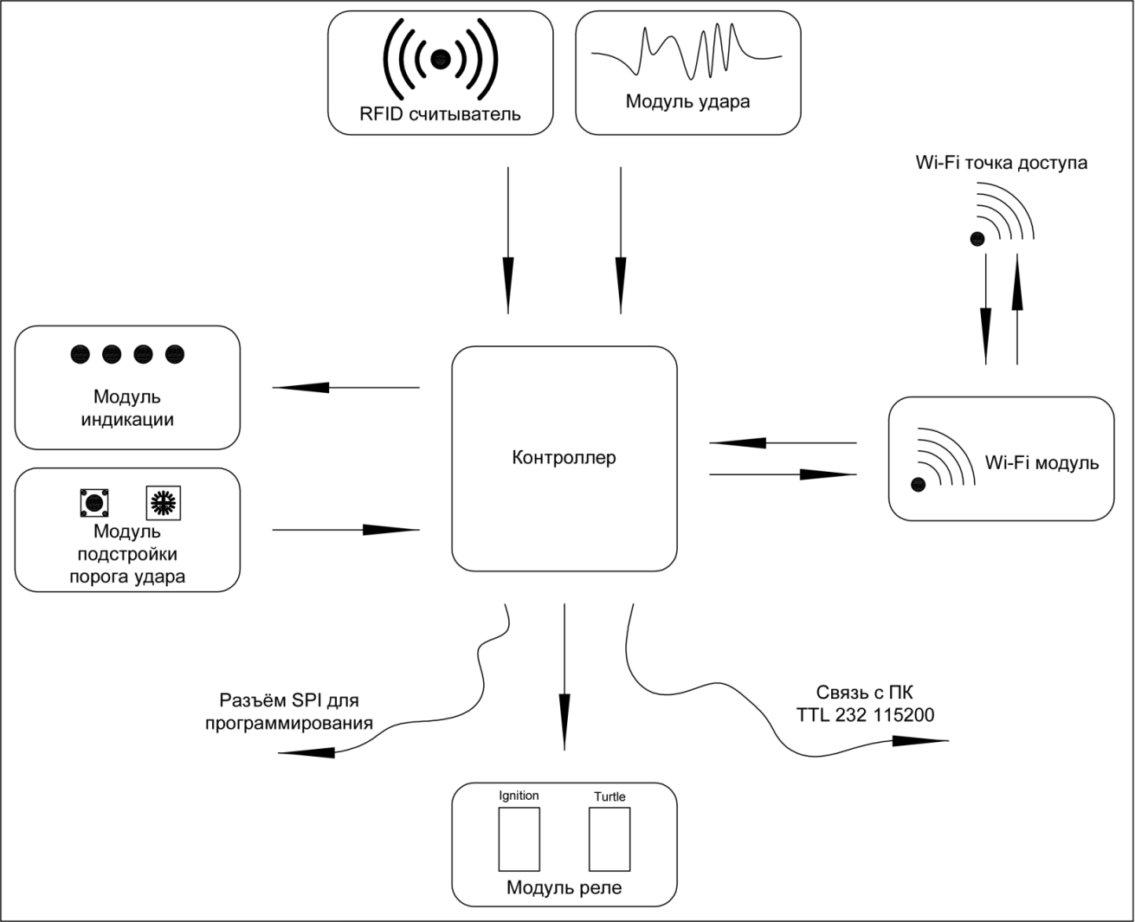
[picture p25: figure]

Рисунок 3. Общая структурная схема УБД

3. Сборка УБД

Для сборки УБД потребуется:

- Корпус
- Кабельный ввод PG7 (чёрный)
- Собранная плата устройства
- Винт М3 4шт
- Стойка М3х5 4шт
- Вспененный материал ~5мм толщиной
- Пьезоэлемент
- Полоска клея ~ 30x30

На рисунке 4 показана последовательность сборки УБД

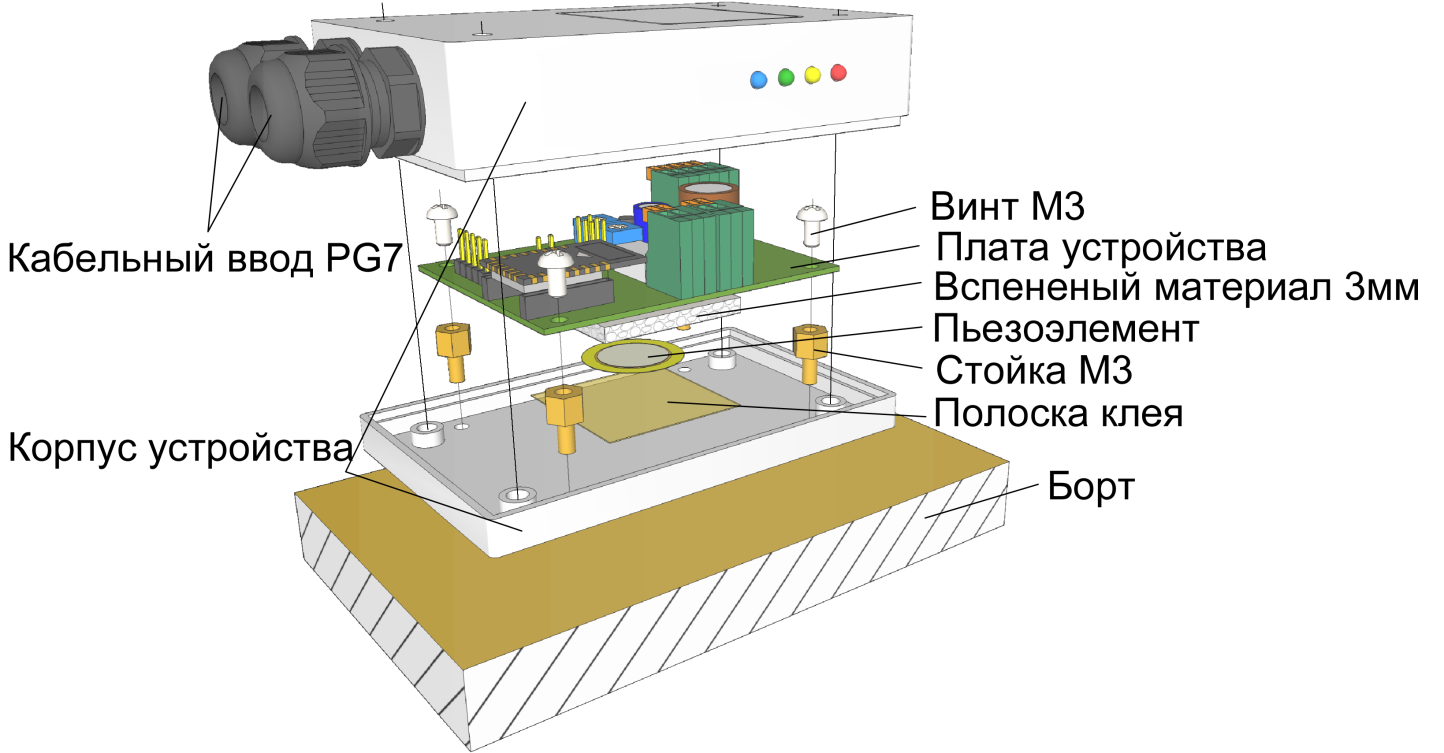
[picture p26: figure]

Рисунок 4. Последовательность сборки УБД

На рисунке 5 приведены размеры шаблонов для крепления кабельных вводов и платы устройства

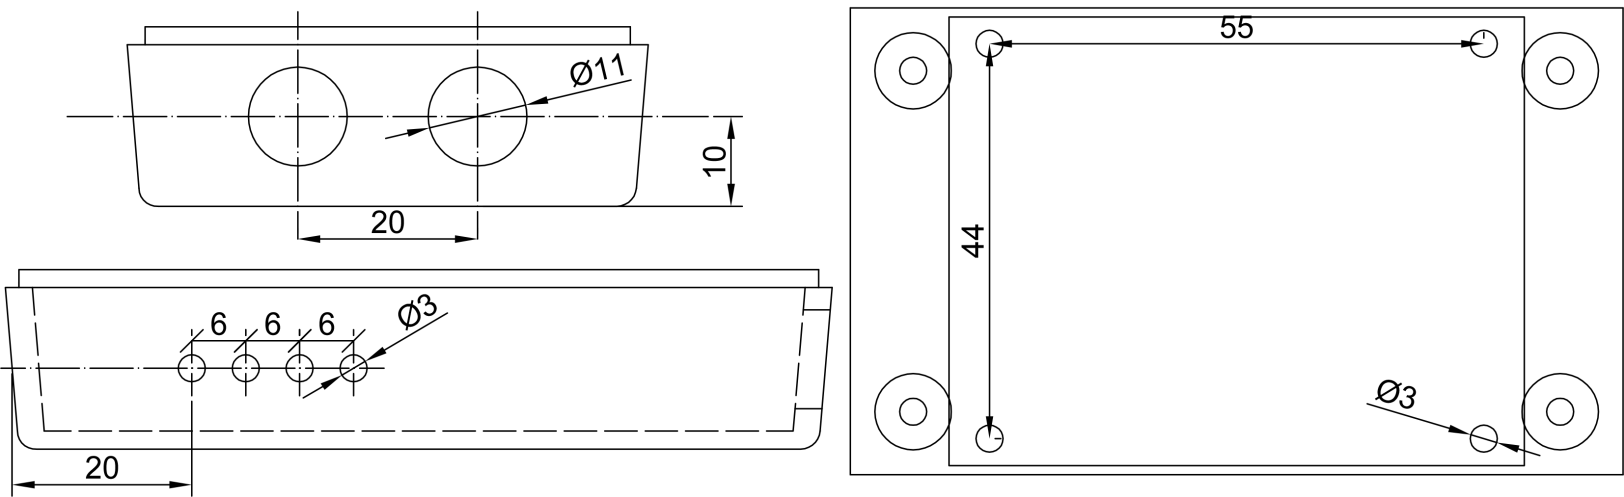
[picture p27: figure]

Рисунок 5. Шаблоны для сверления отверстий

Частично собранное УБД показано на рисунке 6

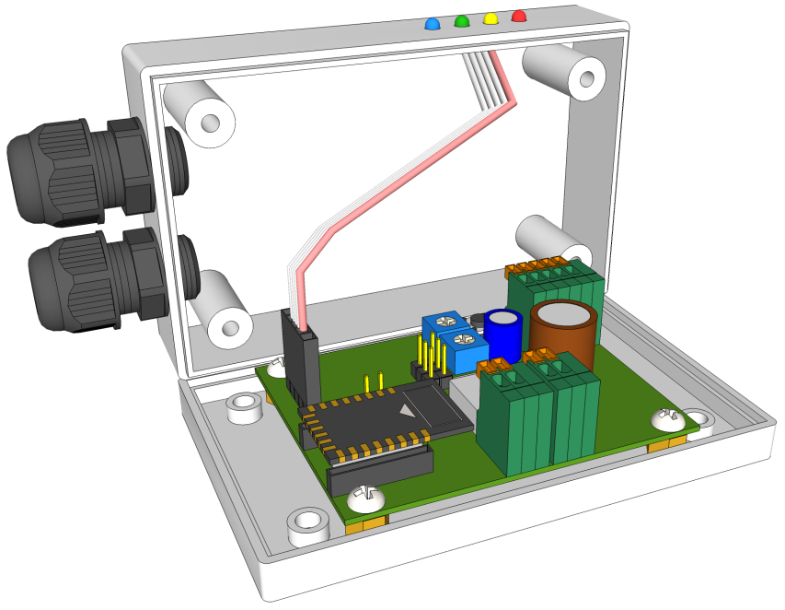
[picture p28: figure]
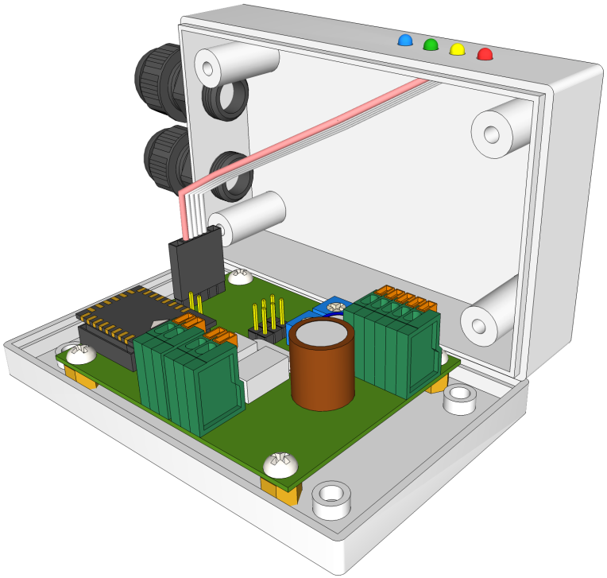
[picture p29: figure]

Рисунок 6. УБД в сборе

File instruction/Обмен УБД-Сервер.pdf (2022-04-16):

## ID , RFID , Udar : : start start

Разделительные символы

Идентификатор стартовой строки "start"

ID-устройства 1..255

Текущая RFID-карта

Флаг удара
1-зафиксирован удар
0-нет удара

## RFID-List : RFID_List_fixed_len_blabla CRC

Идентификатор пакета с RFID-картами

Список RFID-карт

160 байт

сумма пакета
Контрольная

0 1 2 3 4 5 6 7 ... 136 137 138 139 140 141 142 143 ...

RFID-USER 1 RFID-USER 2 RFID-USER 34 RFID-MASTER 1

156 157 158 159

RFID-MASTER 5

Список RFID-карт 160 байт

Стартовая строка от УБД

Список разрешённых RFID-карт от сервера

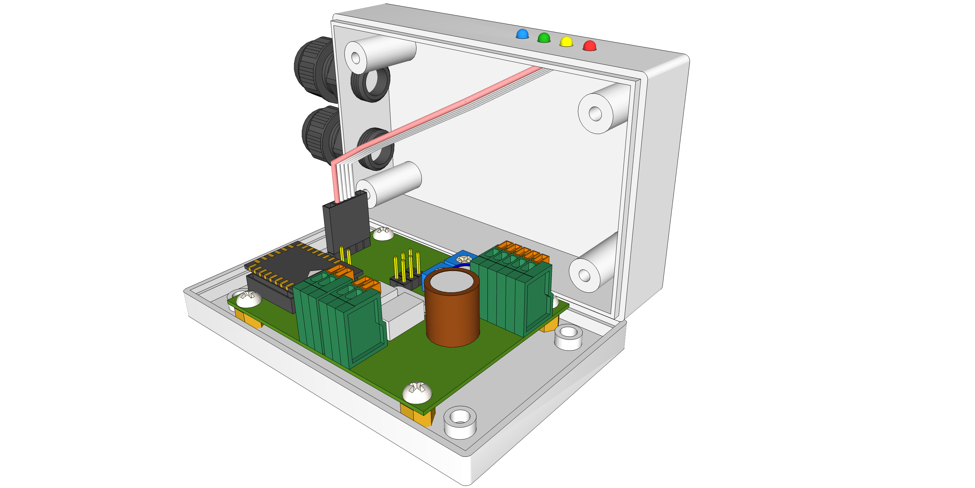
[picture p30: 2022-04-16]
instruction/В сборе 2.png

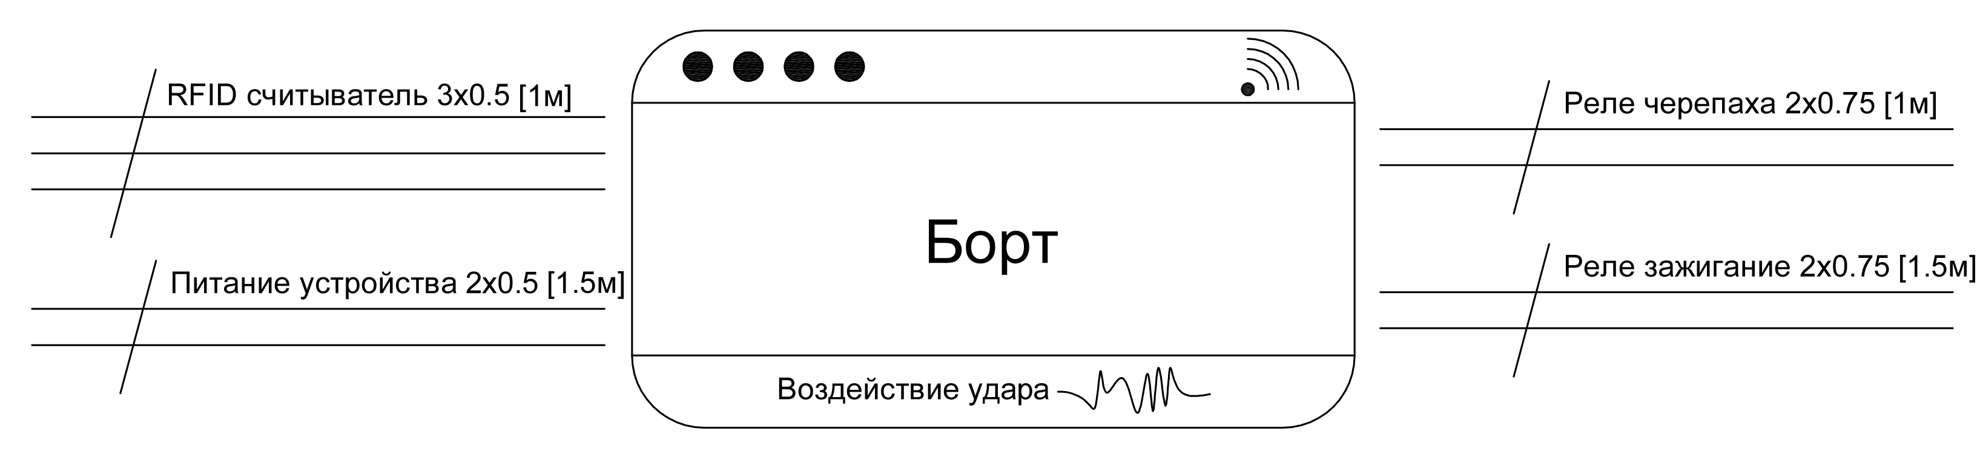
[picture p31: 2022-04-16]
instruction/Сечение кабелей.png

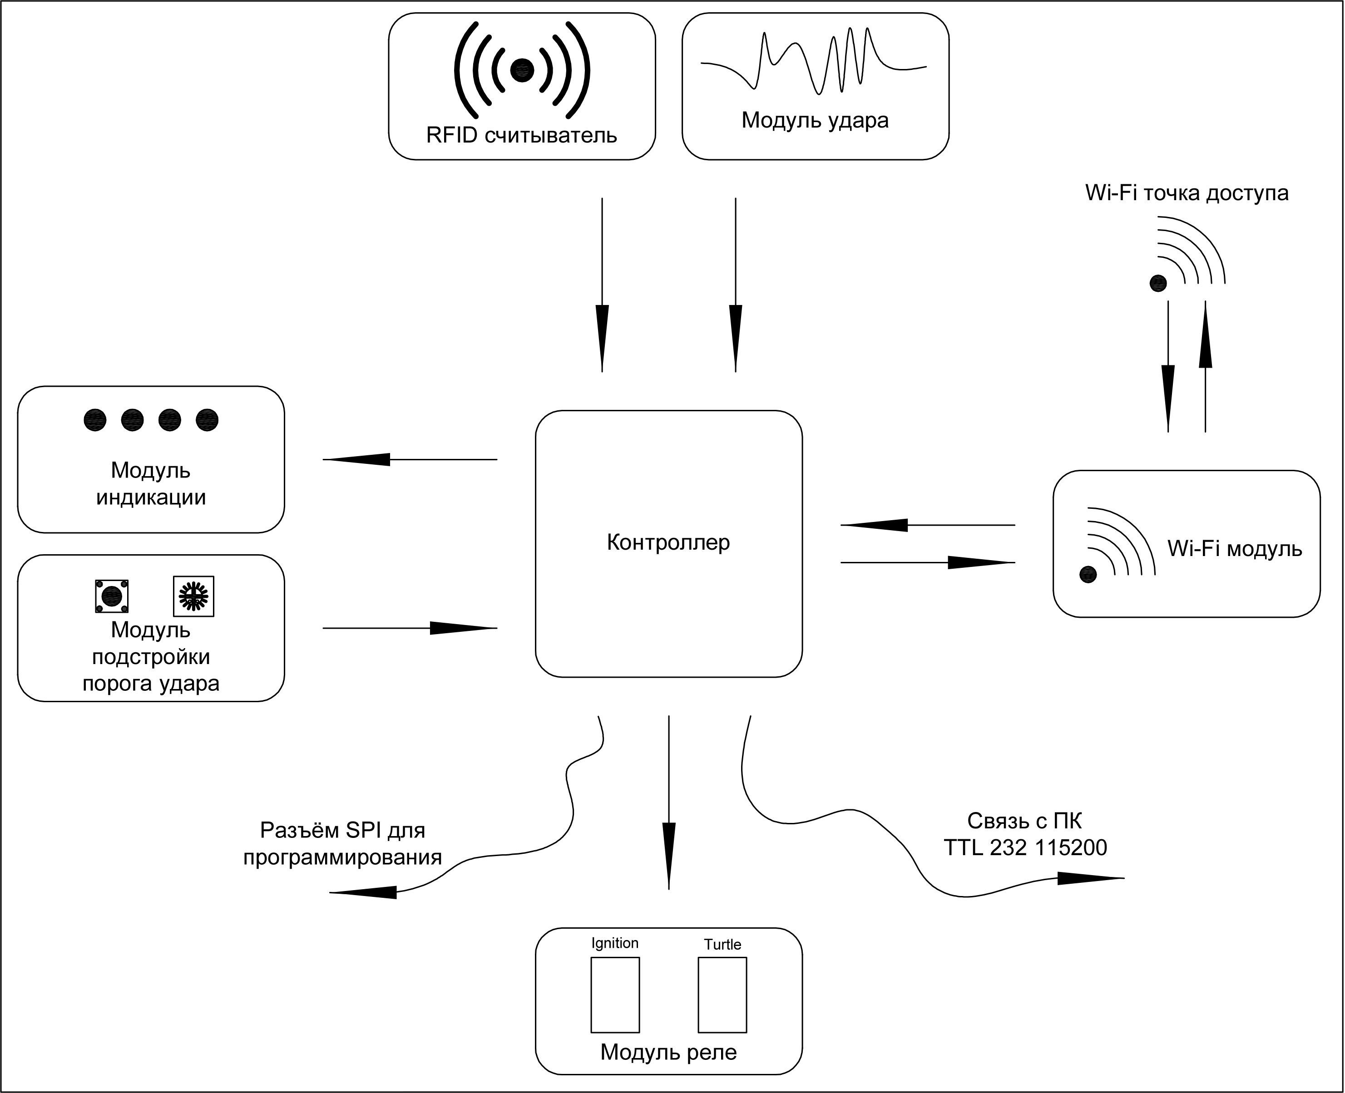
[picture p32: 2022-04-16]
instruction/Структура контроллера.png

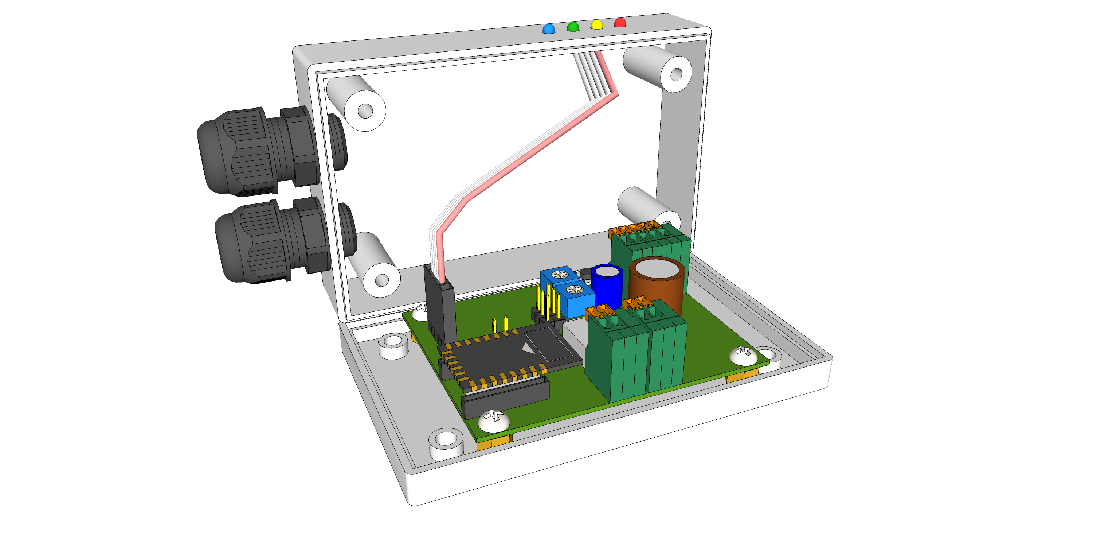
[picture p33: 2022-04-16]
instruction/В сборе 1.png

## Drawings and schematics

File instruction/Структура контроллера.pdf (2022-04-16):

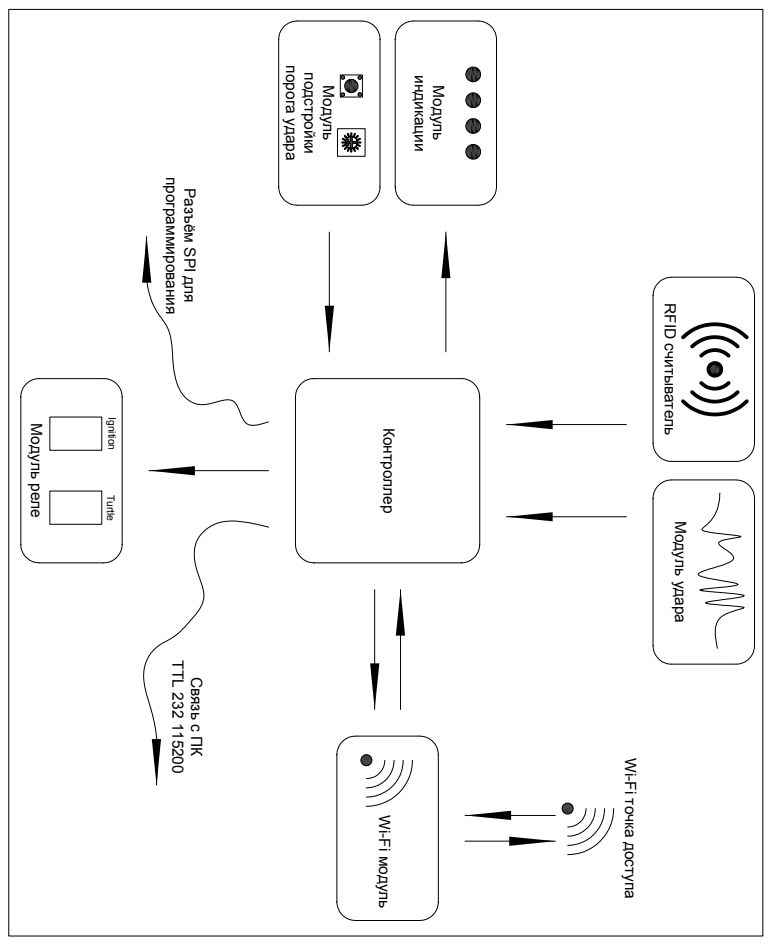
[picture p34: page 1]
Модуль; индикации; подстройки; порога удара; Модуль реле; Ignition Turtle; Модуль удара; Связь с ПК; RFID считыватель

TTL 232 115200 Разъём SPI для программирования

Контроллер Wi-Fi модуль

Wi-Fi точка доступа

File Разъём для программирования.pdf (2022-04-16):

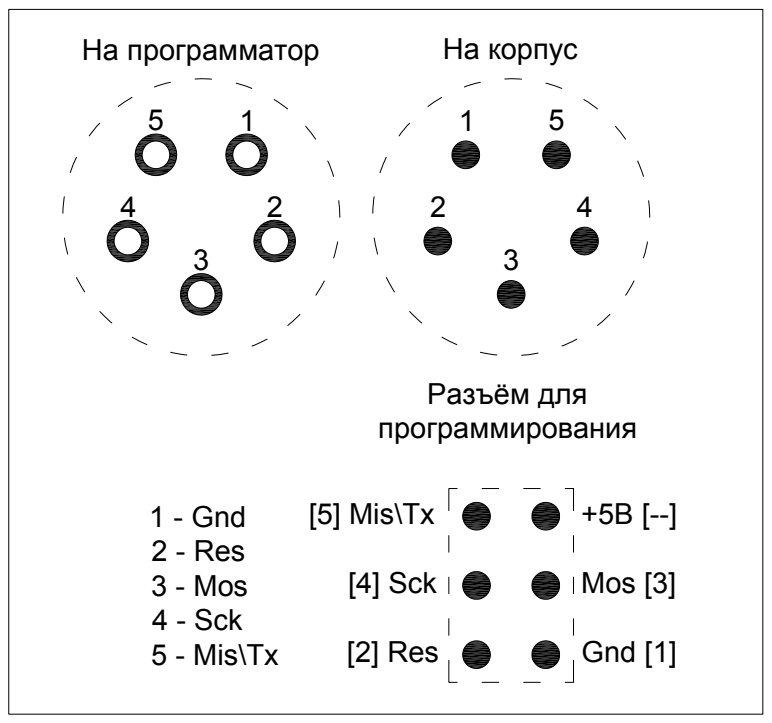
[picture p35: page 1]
На программатор; На корпус; [5] Mis\Tx; [4] Sck; [2] Res; Mos [3]; Gnd [1]; Разъём для программирования; 1 - Gnd 2 - Res 3 - Mos 4 - Sck 5 - Mis\Tx

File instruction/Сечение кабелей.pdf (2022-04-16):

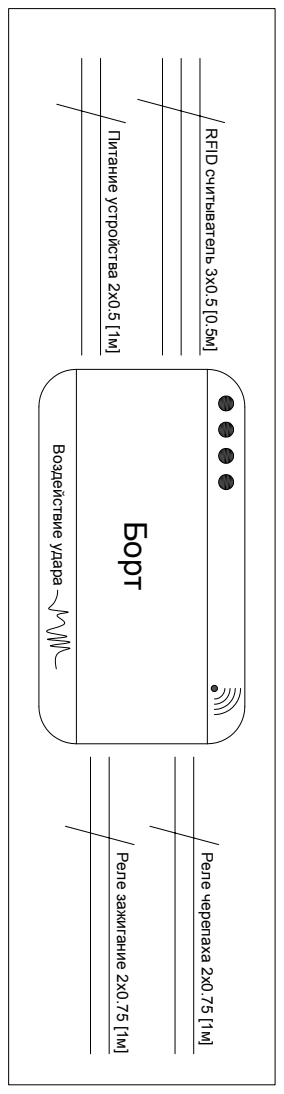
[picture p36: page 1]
Борт; Воздействие удара; Питание устройства 2x0.5 [1м]; RFID считыватель 3x0.5 [0.5м]; Реле зажигание 2x0.75 [1м]; Реле черепаха 2x0.75 [1м]

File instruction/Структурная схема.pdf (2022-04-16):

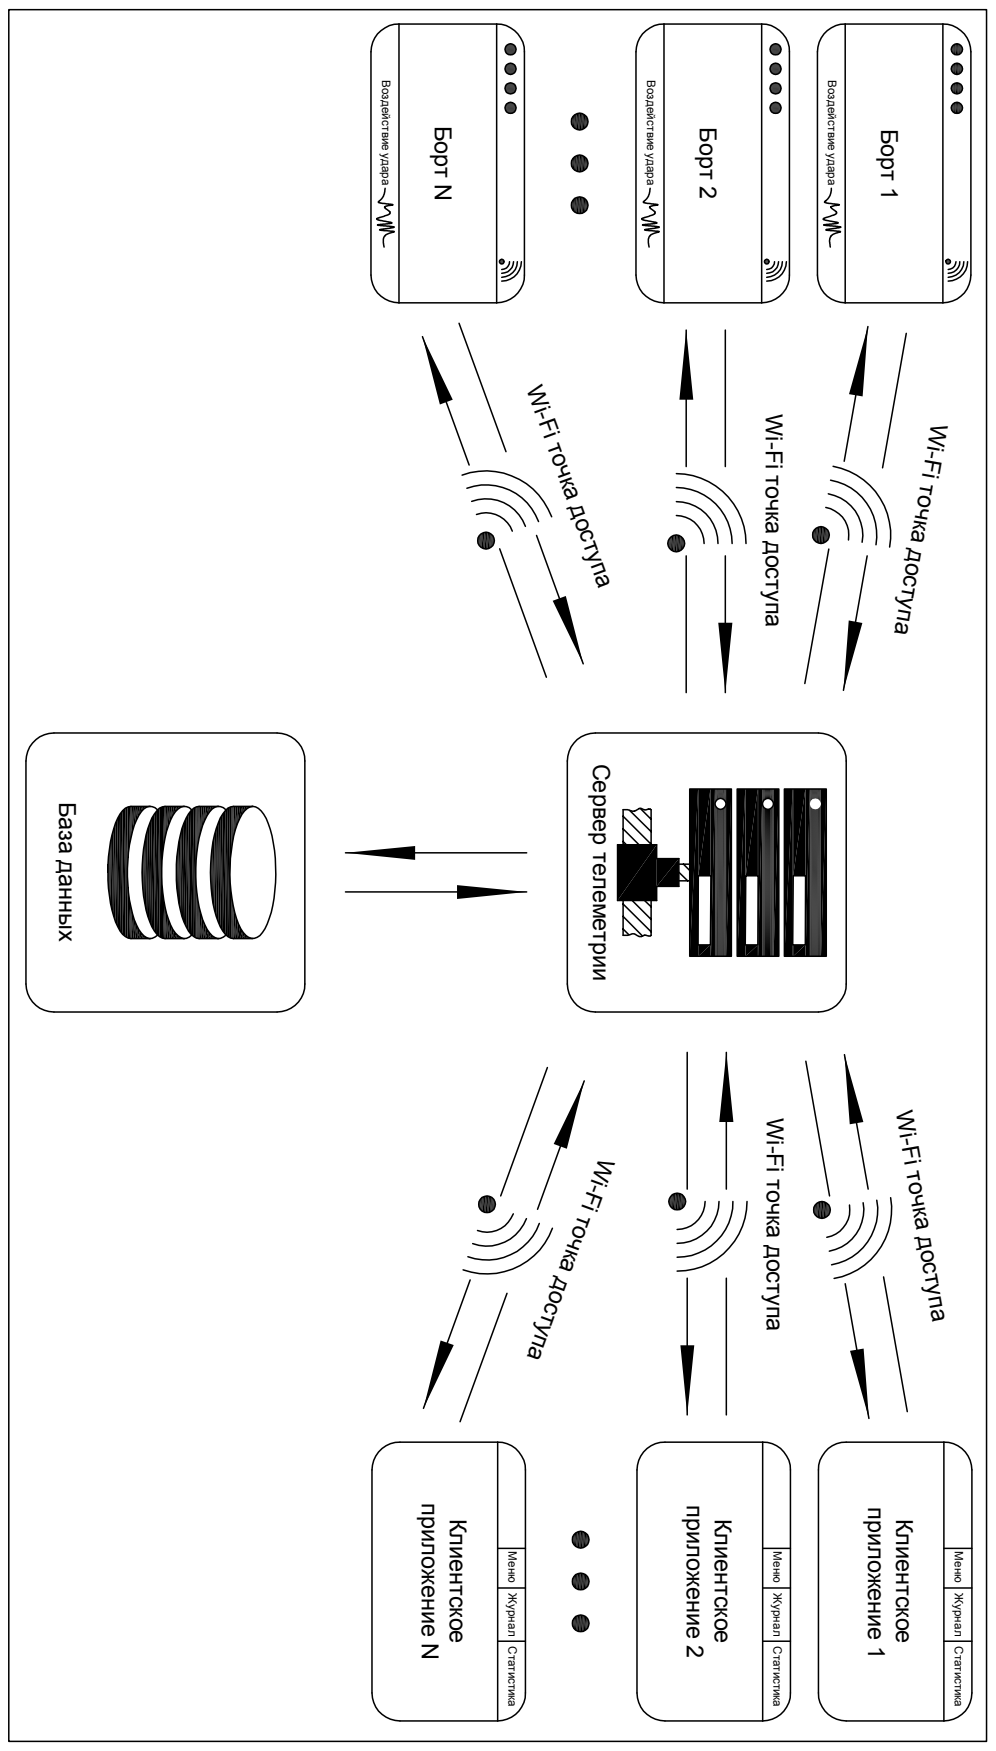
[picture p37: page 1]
Сервер телеметрии; Клиентское; приложение 2; приложение N; приложение 1; Борт 2; Борт N; Борт 1; База данных; Воздействие удара

Wi-Fi точка доступа

Меню Журнал Статистика

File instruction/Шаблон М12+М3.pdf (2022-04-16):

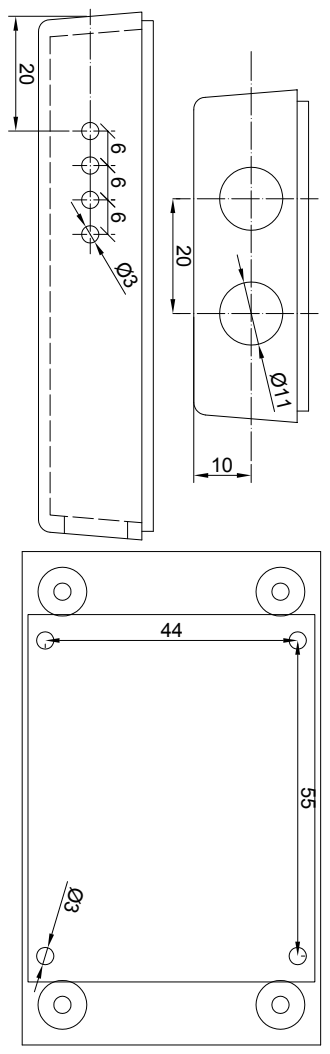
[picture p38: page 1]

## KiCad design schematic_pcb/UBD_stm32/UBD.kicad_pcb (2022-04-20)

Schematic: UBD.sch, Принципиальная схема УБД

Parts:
C1: 100uF; C_Radial_D12.5mm_H20.0mm_P5.00mm
C2, C4, C5: 100n; C_0603_1608Metric
C3, C7: 220uF; CP_Elec_8x10.5
C6, C12, C13: 1uF; C_0603_1608Metric
C8: 10uF; C_0603_1608Metric
C9: 0.01uF; C_0603_1608Metric
C10: 22uF; C_0603_1608Metric
C11: 1000pF; C_0603_1608Metric
D1, D2, D3, D5, D6: Диод Шоттки; D_SMA
D4: LED; LED_0805_2012Metric
D7: Светодиод красный; LED_D3.0mm_Horizontal_O1.27mm_Z2.0mm
D8: Светодиод жёлтый; LED_D3.0mm_Horizontal_O1.27mm_Z2.0mm
D9: Светодиод зелёный; LED_D3.0mm_Horizontal_O1.27mm_Z2.0mm
D10: Светодиод синий; LED_D3.0mm_Horizontal_O1.27mm_Z2.0mm
D11: SP0503; SOT-143
D12: LIS3DHTR; LGA-16_3x3mm_P0.5mm_LayoutBorder3x5y
D15, D16: Диод Шоттки; D_SOT-23_ANK
F1: Fuse; R_1206_3216Metric
J1: ST-Link; JST_XH_S5B-XH-A_1x05_P2.50mm_Horizontal
J2: Ignition; JST_XH_S2B-XH-A_1x02_P2.50mm_Horizontal
J3: Считыватель; JST_XH_S3B-XH-A_1x03_P2.50mm_Horizontal
J4: USB_B_Micro; USB_Mini-B_Lumberg_2486_01_Horizontal
J5: Turtle; JST_XH_S2B-XH-A_1x02_P2.50mm_Horizontal
J6: Удар; JST_XH_S4B-XH-A_1x04_P2.50mm_Horizontal
J7: Питание; JST_XH_S2B-XH-A_1x02_P2.50mm_Horizontal
K1, K2: NRP-18; Relay_NRP-18
L2: 1500uH; SDR_1006
L3: 10uH; L_Vishay_IHLP-2525
Q1, Q2: BC817; SOT-23
R1, R9, R10: 360; R_0603_1608Metric
R2, R4, R5, R6, R7, R8, R11, R12, R13, R25: 10k; R_0603_1608Metric
R3: 330; R_Array_Convex_4x0603
R22: 100k; R_0603_1608Metric
R23: 1.6k; R_0603_1608Metric
R24: 30k; R_0603_1608Metric
SW1, SW2: SW_DIP_x06; SW_DIP_SPSTx06_Slide_Omron_A6H-6101_W6.15mm_P1.27mm
U1: STM32F103C8Tx; LQFP-48_7x7mm_P0.5mm
U2: LM2576HVS-12; TO-263-5_TabPin3
U3: ESP-12F; ESP-12E
U4: CP2102; QFN-28-1EP_5x5mm_P0.5mm_EP3.35x3.35mm
U5: AT24CS256; SOIC-8_3.9x4.9mm_P1.27mm
U9: LM2734Y; TSOT-23-6
Y1: 8.0MHz; Crystal_SMD_3225-2Pin_3.2x2.5mm_HandSoldering

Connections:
+3V3: C6.1, C7.1, C10.2, C11.2, C12.1, C13.1, D12.1, D12.8, D12.14, D16.2 (A), J1.2, J6.4, L3.2, R1.2, R2.1, R4.1, R7.2, R8.2, R11.1, R12.2, R13.2, R23.1, U1.9 (VDDA), U1.24 (VDD), U1.36 (VDD), U1.48 (VDD), U3.8 (VCC), U4.6 (VDD), U5.8 (VCC)
+5V: D2.1 (K), D11.4 (K), U4.7 (REGIN), U4.8 (VBUS)
+12V: C3.1, C8.2, D5.1 (K), D6.1 (K), J3.2, K1.2, K2.2, L2.2, R22.1, U2.4 (FB), U9.5 (VIN)
/CLK: J1.4, U1.37 (PA14)
/Data0: J3.3, R4.2, U1.16 (PA6)
/Fb: C11.1, R24.1, R25.2, U9.3 (FB)
/Ig: R10.2, U1.15 (PA5)
/Ig_NO1: J2.2, K1.1
/Ig_NO2: J2.1, K1.3
/Led1: D7.2 (A), U1.41 (PB5)
/Led2: D8.2 (A), U1.45 (PB8)
/Led3: D9.2 (A), U1.46 (PB9)
/Led4: D10.2 (A), U1.2 (PC13)
/RXD: U1.30 (PA9), U4.25 (RXD)
/RX_W: U1.12 (PA2), U3.21 (GPIO3/RXD)
/Rst: C5.1, R2.2, U1.7 (NRST)
/Rst_wf: R7.1, U1.11 (PA1), U3.1 (~RST)
/SCL: D12.4, R13.1, U1.42 (PB6), U5.6 (SCL)
/SDA: D12.6, R12.1, U1.43 (PB7), U5.5 (SDA)
/SWD: J1.3, U1.34 (PA13)
/SWO: J1.1, U1.39 (PB3)
/TXD: U1.31 (PA10), U4.26 (TXD)
/TX_W: U1.13 (PA3), U3.22 (GPIO1/TXD)
/Tr: R9.1, U1.14 (PA4)
/Tr_NO1: J5.2, K2.1
/Tr_NO2: J5.1, K2.3
/Tx_ud: J6.2, U1.21 (PB10)
/Udar: J6.3, U1.22 (PB11)
/bit0: SW1.1, U1.32 (PA11)
/bit1: SW1.2, U1.33 (PA12)
/bit2: SW1.3, U1.29 (PA8)
/bit3: SW1.4, U1.28 (PB15)
/bit4: SW1.5, U1.27 (PB14)
/bit5: SW1.6, U1.26 (PB13)
/bit6: SW2.1, U1.25 (PB12)
/bit7: SW2.2, U1.19 (PB1)
/bit8: SW2.3, U1.18 (PB0)
/bit9: SW2.4, U1.17 (PA7)
/bit10: SW2.5, U1.40 (PB4)
/bit11: SW2.6, U1.38 (PA15)
GND: C1.2, C2.2, C3.2, C4.2, C5.2, C6.2, C7.2, C8.1, C10.1, C12.2, C13.2, D3.2 (A), D4.1 (K), D11.1 (A), D12.2, D12.3, D12.5, D12.7, D12.10, D12.12, D12.13, D12.15, D12.16, D15.2 (A), J1.5, J3.1, J4.5, J4.6, J6.1, J7.1, Q1.2 (E), Q2.2 (E), R3.5 (R4.2), R3.6 (R3.2), R3.7 (R2.2), R3.8 (R1.2), R5.2, R6.2, R25.1, SW1.7, SW1.8, SW1.9, SW1.10, SW1.11, SW1.12, SW2.7, SW2.8, SW2.9, SW2.10, SW2.11, SW2.12, U1.8 (VSSA), U1.23 (VSS), U1.35 (VSS), U1.47 (VSS), U2.3 (GND), U2.5 (~ON~/OFF), U3.15 (GND), U3.16 (GPIO15), U4.3 (GND), U4.29 (GND), U5.1 (A0), U5.2 (A1), U5.3 (A2), U5.4 (GND), U5.7 (WP), U9.2 (GND); also elsewhere on the board
unnamed: C1.1, D1.1 (K), U2.1 (VIN)
unnamed: C2.1, U1.6 (PD1), Y1.1
unnamed: C4.1, U1.5 (PD0), Y1.2
unnamed: C9.1, D15.1 (K), L3.1, U9.6 (SW)
unnamed: C9.2, D16.1 (K), U9.1 (BOOST)
unnamed: D1.2 (A), F1.1
unnamed: D2.2 (A), J4.1
unnamed: D3.1 (K), L2.1, U2.2 (OUT)
unnamed: D4.2 (A), R1.1
unnamed: D5.2 (A), K1.5, Q1.3 (C)
unnamed: D6.2 (A), K2.5, Q2.3 (C)
unnamed: D7.1 (K), R3.4 (R4.1)
unnamed: D8.1 (K), R3.3 (R3.1)
unnamed: D9.1 (K), R3.2 (R2.1)
unnamed: D10.1 (K), R3.1 (R1.1)
unnamed: D11.2 (K), J4.2, U4.5 (D-)
unnamed: D11.3 (K), J4.3, U4.4 (D+)
unnamed: F1.2, J7.2
unnamed: Q1.1 (B), R10.1
unnamed: Q2.1 (B), R9.2
unnamed: R5.1, U1.44 (BOOT0)
unnamed: R6.1, U1.20 (PB2)
unnamed: R8.1, U3.3 (EN)
unnamed: R11.2, U4.9 (~RSTb)
unnamed: R22.2, U9.4 (EN)
unnamed: R23.2, R24.2

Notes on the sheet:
Gnd
CLK
SWD
3v3
SWO
i2c addresss 0x30
i2c addresss 0x50

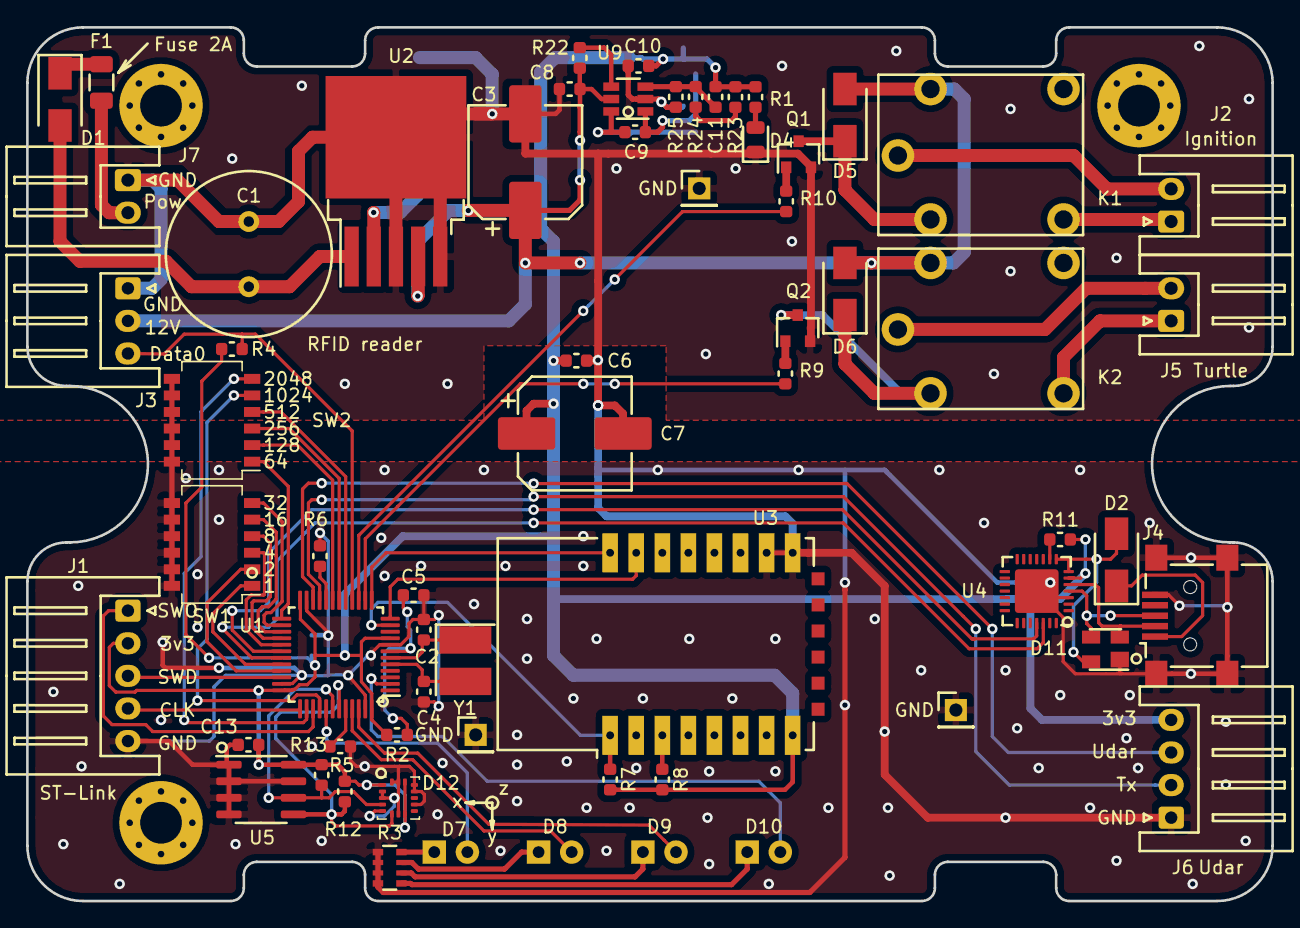
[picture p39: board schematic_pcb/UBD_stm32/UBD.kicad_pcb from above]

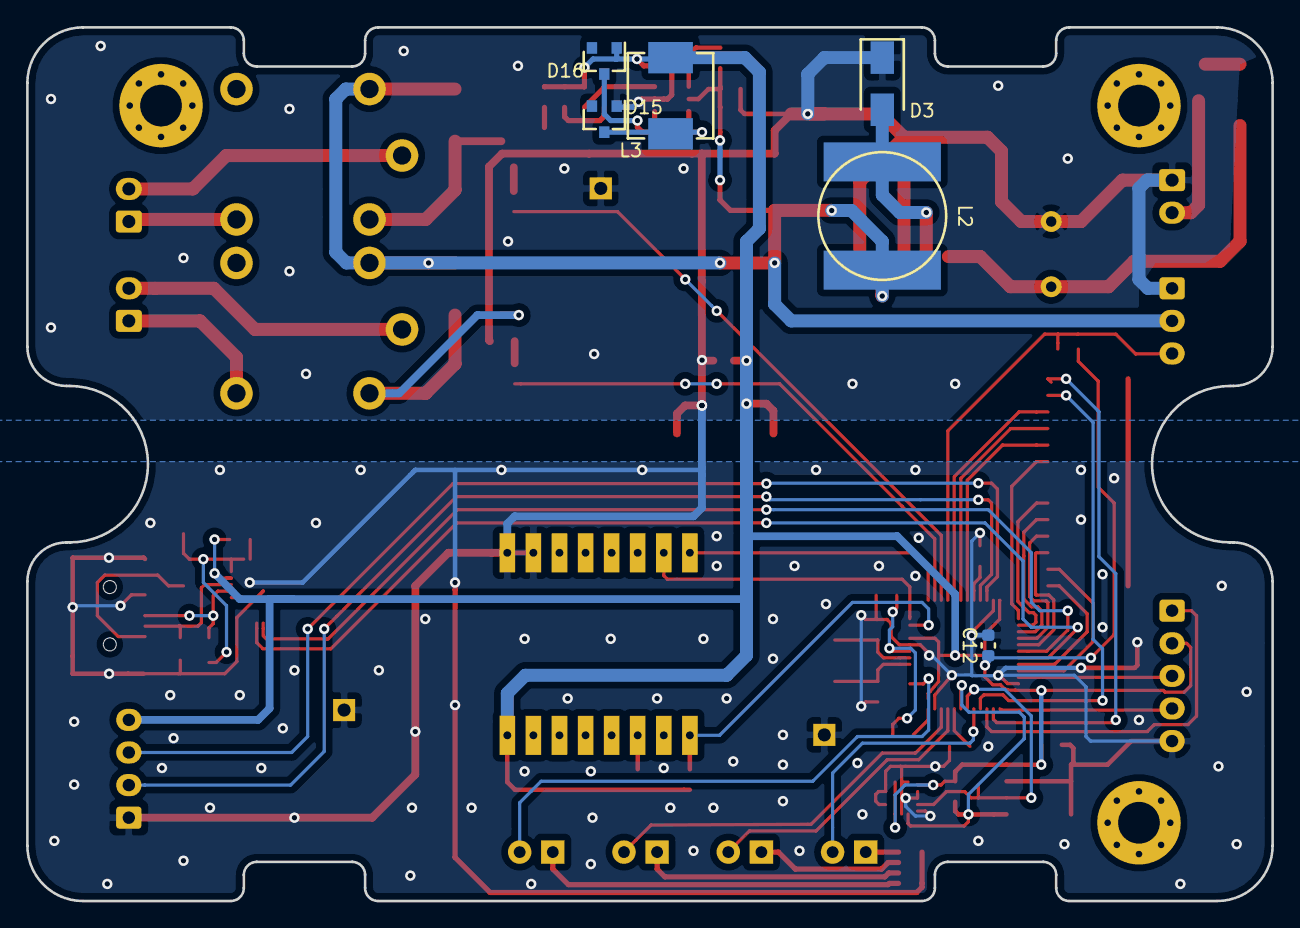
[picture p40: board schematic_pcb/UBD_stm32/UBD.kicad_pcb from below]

Board: 2 copper layers, 95.5 x 67.0 mm, 70 parts (6 on the bottom side), 67 nets.

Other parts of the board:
GND: PinHeader_1x01_P2.54mm_Vertical
GND#2, GND#3: PinHeader_1x01_P2.54mm_Vertical

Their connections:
GND: GND.1, GND#2.1, GND#3.1; also elsewhere on the board

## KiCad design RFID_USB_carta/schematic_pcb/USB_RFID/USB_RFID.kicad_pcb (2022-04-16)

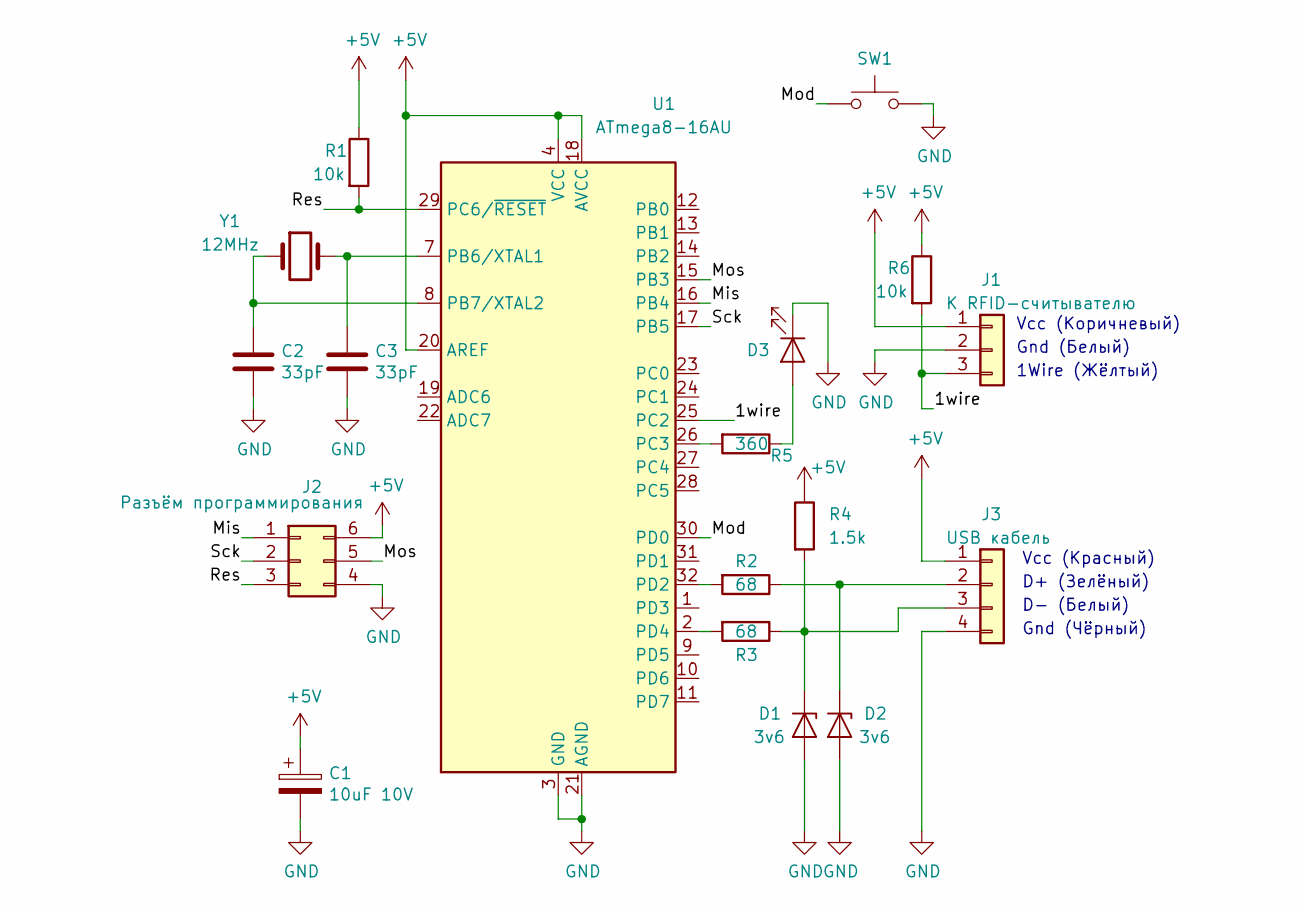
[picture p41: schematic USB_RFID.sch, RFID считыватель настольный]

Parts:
C1: 10uF 10V; CP_EIA-3216-18_Kemet-A
C2, C3: 33pF; C_0805_2012Metric
D1, D2: 3v6; D_MiniMELF
D3: LED; LED_0603_1608Metric
J1: К RFID-считывателю; USB
J2: Разъём программирования; PinHeader_2x03_P2.54mm_Vertical
J3: USB кабель; RFID
R1, R6: 10k; R_0603_1608Metric
R2, R3: 68; R_0603_1608Metric
R4: 1.5k; R_0603_1608Metric
R5: 360; R_0603_1608Metric
SW1: SW_Push; SW_SPST_PTS645
U1: ATmega8-16AU; TQFP-32_7x7mm_P0.8mm
Y1: 12MHz; Crystal_SMD_HC49-SD_HandSoldering

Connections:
+5V: C1.1, J1.1, J2.6, J3.1, R1.1, R4.1, R6.1, U1.4 (VCC), U1.6 (VCC), U1.18 (AVCC), U1.20 (AREF)
/1wire: J1.3, R6.2, U1.25 (PC2)
/Mis: J2.1, U1.16 (PB4)
/Mod: SW1.1, U1.30 (PD0)
/Mos: J2.5, U1.15 (PB3)
/Res: J2.3, R1.2, U1.29 (PC6/~RESET)
/Sck: J2.2, U1.17 (PB5)
GND: C1.2, C2.2, C3.2, D1.2 (A), D2.2 (A), D3.1 (K), J1.2, J2.4, J3.4, SW1.2, U1.3 (GND), U1.5 (GND), U1.21 (AGND)
unnamed: C2.1, U1.8 (PB7/XTAL2), Y1.1
unnamed: C3.1, U1.7 (PB6/XTAL1), Y1.2
unnamed: D1.1 (K), J3.3, R3.1, R4.2
unnamed: D2.1 (K), J3.2, R2.1
unnamed: D3.2 (A), R5.1
unnamed: R2.2, U1.32 (PD2)
unnamed: R3.2, U1.2 (PD4)
unnamed: R5.2, U1.26 (PC3)

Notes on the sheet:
Vcc (Красный)
D+ (Зелёный)
D- (Белый)
Gnd (Чёрный)
1Wire (Жёлтый)
Gnd (Белый)
Vcc (Коричневый)

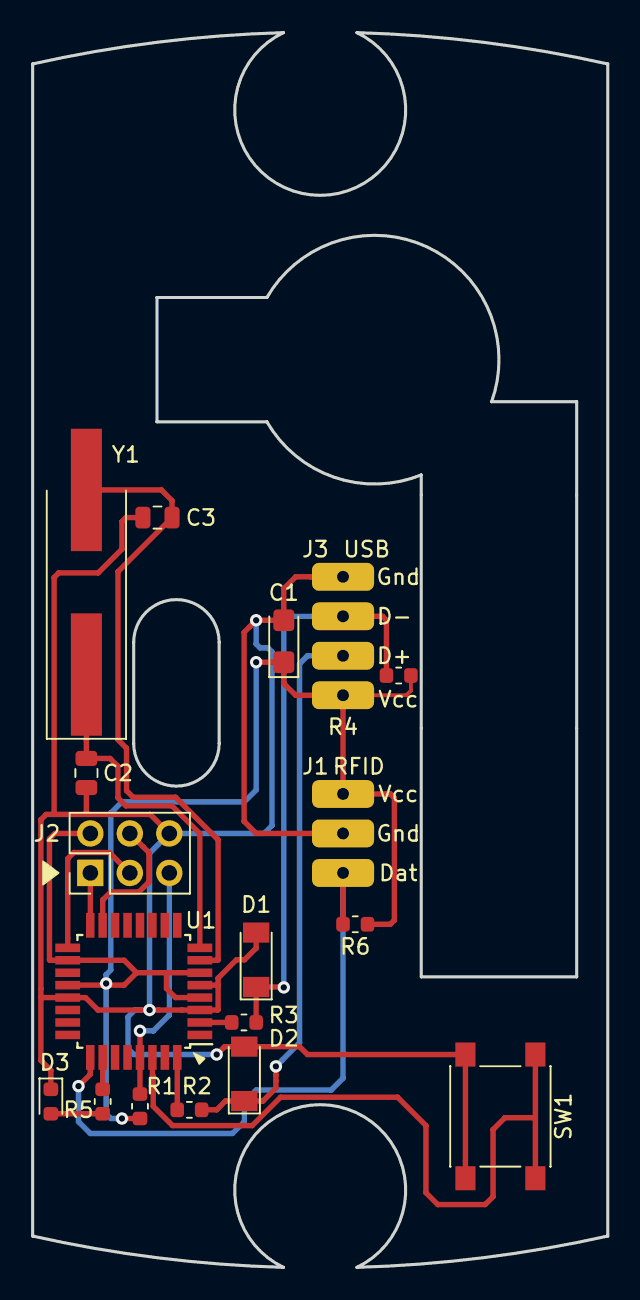
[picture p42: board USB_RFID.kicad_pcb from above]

Board: 2 copper layers, 37.0 x 79.4 mm, 18 parts (0 on the bottom side), 16 nets.

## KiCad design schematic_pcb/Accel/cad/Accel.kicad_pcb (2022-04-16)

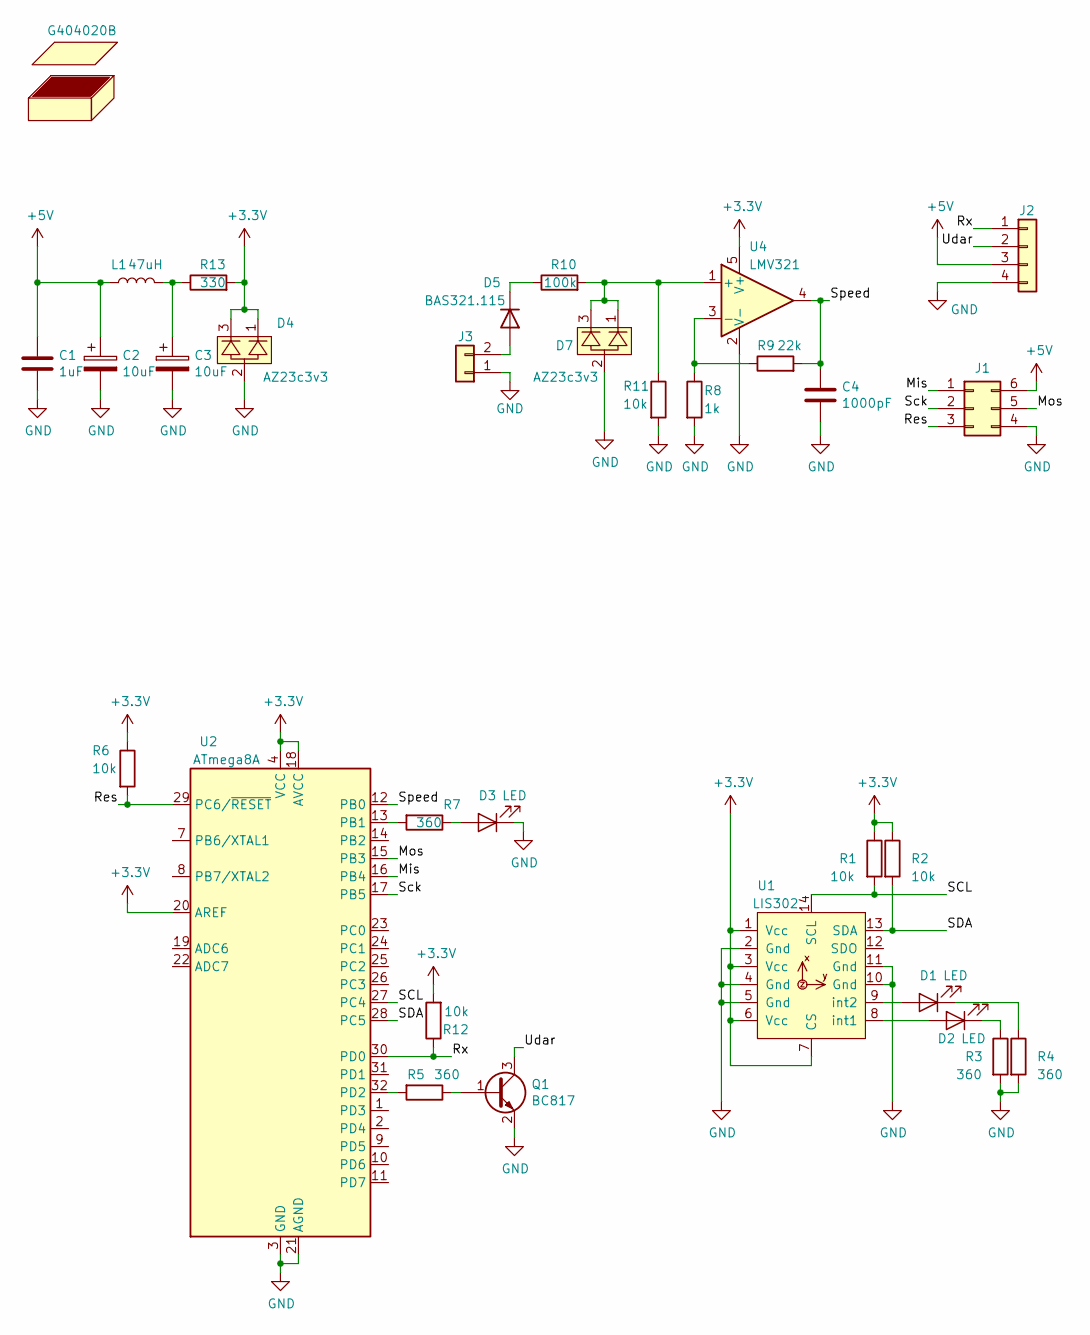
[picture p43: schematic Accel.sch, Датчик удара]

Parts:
C1: 1uF; C_0805_2012Metric
C2, C3: 10uF; CP_EIA-3216-18_Kemet-A
C4: 1000pF; C_0603_1608Metric
D1, D2: LED; LED_0805_2012Metric
D3: LED; LED_D3.0mm_Horizontal_O1.27mm_Z6.0mm
D4, D7: AZ23c3v3; SOT-23
D5: BAS321.115; D_SOD-323_HandSoldering
D6: G404020B; //www.chipdip.ru/product/g404020b
J1: Conn_02x03_Counter_Clockwise; PinHeader_2x03_P2.54mm_Vertical
J2: Conn_01x04; DG308_04
J3: Conn_01x02; DG308_02
L1: 47uH; L_1812_4532Metric
Q1: BC817; SOT-23
R1, R2, R6, R11, R12: 10k; R_0603_1608Metric
R3, R4, R5, R7: 360; R_0603_1608Metric
R8: 1k; R_0603_1608Metric
R9: 22k; R_0603_1608Metric
R10: 100k; R_0603_1608Metric
R13: 330; R_0805_2012Metric
U1: LIS302; LGA-14_3x5mm_P0.8mm_LayoutBorder1x6y
U2: ATmega8A; TQFP-32_7x7mm_P0.8mm
U4: LMV321; SOT-23-5

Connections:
+3V3: D4.1, D4.3, R1.1, R2.1, R6.1, R12.2, R13.2, U1.1 (Vcc), U1.3 (Vcc), U1.6 (Vcc), U1.7 (CS), U2.4 (VCC), U2.6 (VCC), U2.18 (AVCC), U2.20 (AREF), U4.5 (V+)
+5V: C1.1, C2.1, J1.6, J2.3, L1.1
/Mis: J1.1, U2.16 (PB4)
/Mos: J1.5, U2.15 (PB3)
/Res: J1.3, R6.2, U2.29 (PC6/~RESET)
/Rx: J2.1, R12.1, U2.30 (PD0)
/SCL: R1.2, U1.14 (SCL), U2.27 (PC4)
/SDA: R2.2, U1.13 (SDA), U2.28 (PC5)
/Sck: J1.2, U2.17 (PB5)
/Speed: C4.1, R9.2, U2.12 (PB0), U4.4
/Udar: J2.2, Q1.3 (C)
GND: C1.2, C2.2, C3.2, C4.2, D3.1 (K), D4.2, D7.2, J1.4, J2.4, J3.1, Q1.2 (E), R3.2, R4.2, R8.2, R11.2, U1.2 (Gnd), U1.4 (Gnd), U1.5 (Gnd), U1.10 (Gnd), U1.11 (Gnd), U2.3 (GND), U2.5 (GND), U2.21 (AGND), U4.2 (V-)
unnamed: C3.1, L1.2, R13.1
unnamed: D1.1 (K), R4.1
unnamed: D1.2 (A), U1.9 (int2)
unnamed: D2.1 (K), R3.1
unnamed: D2.2 (A), U1.8 (int1)
unnamed: D3.2 (A), R7.1
unnamed: D5.1 (A), J3.2
unnamed: D5.2 (K), R10.1
unnamed: D7.1, D7.3, R10.2, R11.1, U4.1 (+)
unnamed: Q1.1 (B), R5.1
unnamed: R5.2, U2.32 (PD2)
unnamed: R7.2, U2.13 (PB1)
unnamed: R8.1, R9.1, U4.3 (-)

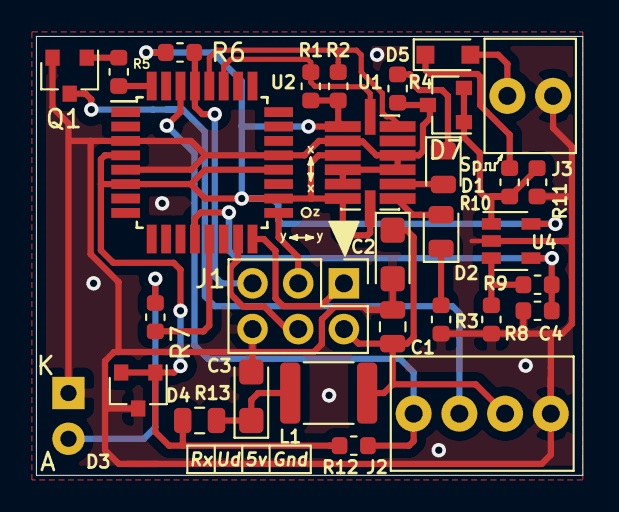
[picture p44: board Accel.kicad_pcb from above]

Board: 2 copper layers, 30.4 x 24.4 mm, 31 parts (0 on the bottom side), 25 nets.

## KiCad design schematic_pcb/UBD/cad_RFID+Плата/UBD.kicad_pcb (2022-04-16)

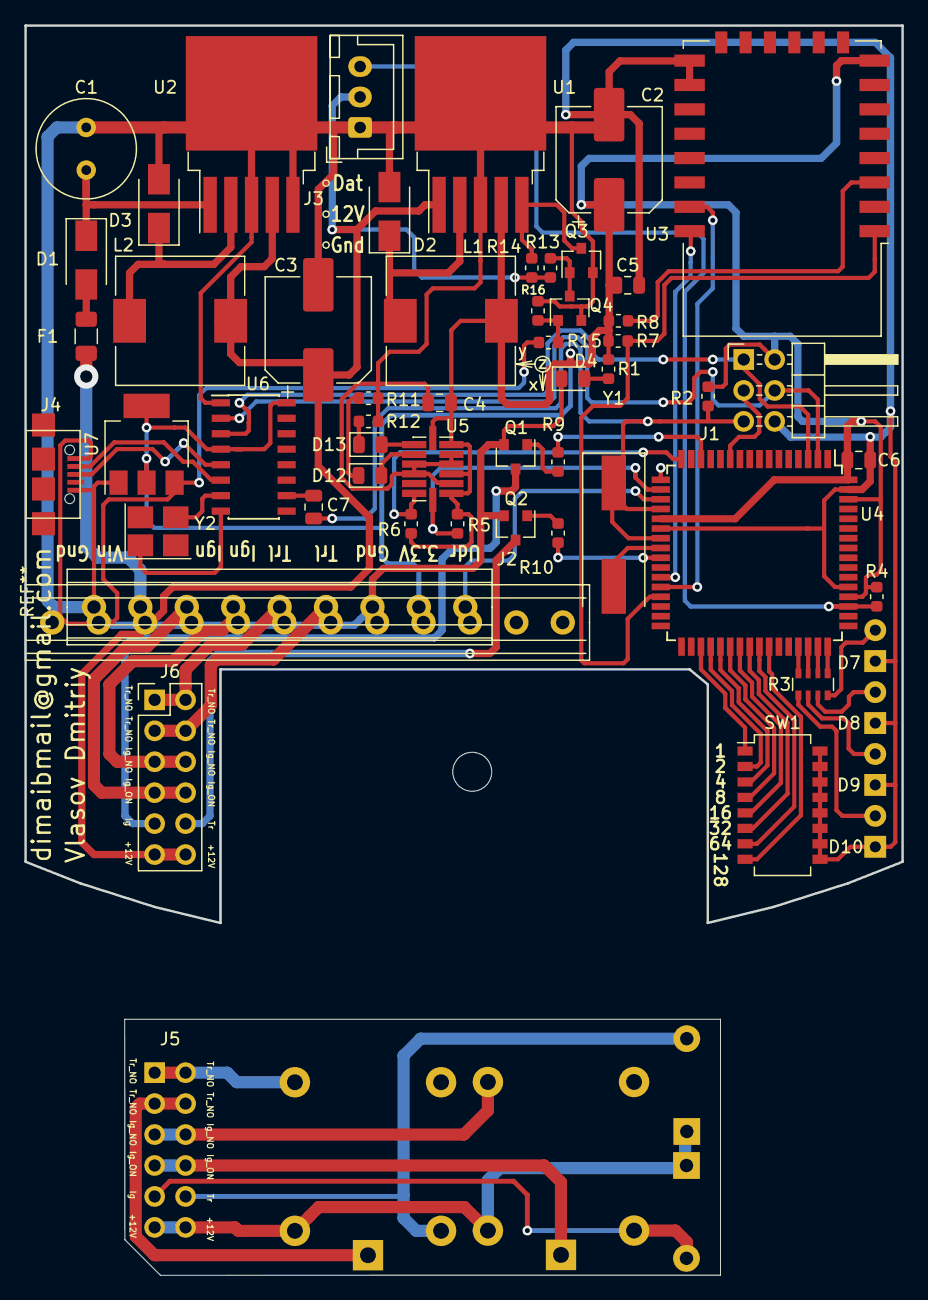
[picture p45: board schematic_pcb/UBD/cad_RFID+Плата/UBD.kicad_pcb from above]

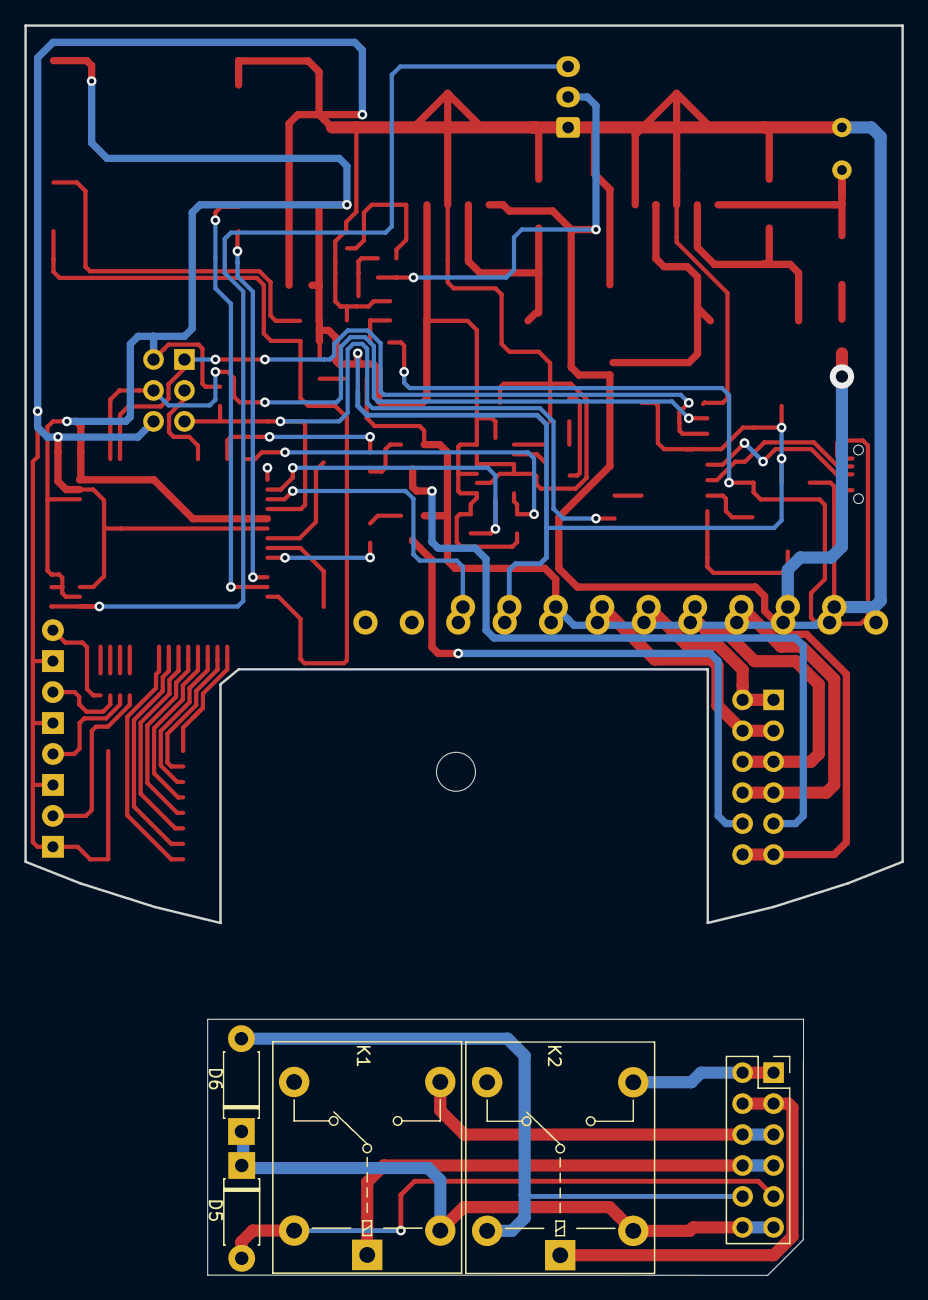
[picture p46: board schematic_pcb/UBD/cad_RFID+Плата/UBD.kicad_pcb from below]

Board: 2 copper layers, 72.0 x 73.7 mm, 60 parts (5 on the bottom side), 69 nets.

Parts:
C1: 100; C_Radial_D8.0mm_H11.5mm_P3.50mm
C2, C3: 220; CP_Elec_8x10.5
C4, C5, C6: 1uF; C_0805_2012Metric
C7: 100nF; C_0805_2012Metric
D1, D2, D3: D_Schottky; D_SMA
D4: LED; LED_0805_2012Metric
D5, D6: D_Schottky; D_DO-41_SOD81_P7.62mm_Horizontal
D7, D8, D9, D10: Red; LED_D3.0mm_Horizontal_O1.27mm_Z2.0mm
D12, D13: Red; LED_0805_2012Metric
F1: Fuse; R_1206_3216Metric
J1: Для программирования; PinHeader_2x03_P2.54mm_Horizontal
J2: Входной клемник; DG_381_9
J3: Считыватель; JST_XH_B3B-XH-A_1x03_P2.50mm_Vertical
J4: USB_B_Micro; USB_Micro
J5: На релейной плате; PinSocket_2x06_P2.54mm_Vertical
J6: На основной плате; PinHeader_2x06_P2.54mm_Vertical
K1, K2: G5LE-1; Relay_SPDT_Omron-G5LE-1
L1: 1000; L_10.4x10.4_H4.8
L2: 2200; L_10.4x10.4_H4.8
Q1, Q2, Q3, Q4: BC817; SOT-23
R1, R7, R8, R9, R10, R11, R12, R15: 360; R_0603_1608Metric
R2, R4, R5, R6, R14, R16: 10k; R_0603_1608Metric
R3: 360; R_Array_Convex_4x0603
R13: 1k; R_0603_1608Metric
SW1: Выбор адреса; SW_DIP_SPSTx08_Slide_Omron_A6H-8101_W6.15mm_P1.27mm
U1: LM2576HVS-3.3; TO-263-5_TabPin3
U2: LM2576HVS-12; TO-263-5_TabPin3
U3: ESP-12F; ESP-12E
U4: ATmega128-16AU; TQFP-64_14x14mm_P0.8mm
U5: LIS302; LGA-14_3x5mm_P0.8mm_LayoutBorder1x6y
U6: CH340G; SOIC-16_3.9x9.9mm_P1.27mm
U7: AP1117-33; SOT-223-3_TabPin2
Y1: 14.7456MHz; Crystal_SMD_HC49-SD
Y2: 12MHz; Crystal_SMD_3225-4Pin_3.2x2.5mm_HandSoldering

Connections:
+3V3: C2.1, C4.1, C5.1, C6.1, J1.6, J2.8, L1.2, R1.2, R2.1, R4.1, R5.1, R6.1, R7.2, R8.2, U1.4, U3.8, U4.21, U4.52, U4.62, U4.64, U5.1, U5.3, U5.6, U5.7, U6.4, U6.16, U7.2
+5V: J4.1, R15.1, U7.3
+12V: C3.1, J3.2, J6.6, J6.7, L2.2, R13.1, R14.2, U1.1, U2.4
/+12_Rel: D5.1, D6.1, J5.6, J5.7, K1.2, K2.2
/+Vin: F1.2, J2.2
/Data0: J3.3, R4.2, U4.51
/Ig: D5.2, J5.5, K1.5
/Ig_NO1: J2.3, J6.4, J6.9
/Ig_NO2: J2.4, J6.3, J6.10
/Ig_NO_1: J5.4, J5.9, K1.1
/Ig_NO_2: J5.3, J5.10, K1.3
/Igg: J6.5, Q1.3
/Mis: J1.1, U4.3, U6.3
/Mos: J1.5, U4.2, U6.2
/RXD: U3.21, U4.28
/Rst: C7.1, J1.3, R2.2, U4.20
/Rst_wf: R7.1, U3.1, U4.29
/SCL: R5.2, U4.18, U5.14
/SDA: R6.2, U4.16, U5.13
/Sck: J1.2, U4.11
/TXD: U3.22, U4.27
/Tr: D6.2, J5.8, K2.5
/Tr_NO1: J2.6, J6.2, J6.11
/Tr_NO2: J2.5, J6.1, J6.12
/Tr_NO_1: J5.2, J5.11, K2.1
/Tr_NO_2: J5.1, J5.12, K2.3
/Trr: J6.8, Q2.3
/Udar: J2.9, U4.19
GND: C1.2, C2.2, C3.2, C4.2, C5.2, C6.2, D2.2, D3.2, D4.1, D7.1, D8.1, D9.1, D10.1, J1.4, J2.1, J2.7, J3.1, J4.5, Q1.2, Q2.2, Q3.2, Q4.2, R11.1, R12.1, R16.2, SW1.9, SW1.10, SW1.11, SW1.12, SW1.13, SW1.14, SW1.15, SW1.16, U1.3, U2.3, U2.5, U3.15, U3.16, U4.22, U4.53, U4.63, U5.2, U5.4, U5.5, U5.10, U5.11, U6.1, U7.1
unnamed: C1.1, D1.1, U2.1
unnamed: C7.2, U6.10
unnamed: D1.2, F1.1
unnamed: D2.1, L1.1, U1.2
unnamed: D3.1, L2.1, U2.2
unnamed: D4.2, R1.1
unnamed: D7.2, R3.8
unnamed: D8.2, R3.7
unnamed: D9.2, R3.6
unnamed: D10.2, R3.5
unnamed: D12.1, R11.2
unnamed: D12.2, U5.9
unnamed: D13.1, R12.2
unnamed: D13.2, U5.8
unnamed: J4.2, U6.6
unnamed: J4.3, U6.5
unnamed: Q1.1, R9.2
unnamed: Q2.1, R10.1
unnamed: Q3.1, Q4.3, R13.2
unnamed: Q3.3, R14.1, U1.5
unnamed: Q4.1, R15.2, R16.1
unnamed: R3.1, U4.48
unnamed: R3.2, U4.47
unnamed: R3.3, U4.46
unnamed: R3.4, U4.45
unnamed: R8.1, U3.3
unnamed: R9.1, U4.14
unnamed: R10.2, U4.25
unnamed: SW1.1, U4.35
unnamed: SW1.2, U4.36
unnamed: SW1.3, U4.37
unnamed: SW1.4, U4.38
unnamed: SW1.5, U4.39
unnamed: SW1.6, U4.40
unnamed: SW1.7, U4.41
unnamed: SW1.8, U4.42
unnamed: U4.23, Y1.1
unnamed: U4.24, Y1.2
unnamed: U6.7, Y2.2
unnamed: U6.8, Y2.1

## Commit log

2022-04-16 add RFID_READ
    [KLAVA_PRIMER.CFG, Klava_primer.obj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]
2022-04-17 del Major
    [Major подготовка к монтажу.xlsx, Список бортов.xls]
2022-04-17 del programm usb_hid
    [KLAVA_PRIMER.CFG, Klava_primer.obj]
2022-04-20 edit screen
    [UBD.kicad_pcb]
